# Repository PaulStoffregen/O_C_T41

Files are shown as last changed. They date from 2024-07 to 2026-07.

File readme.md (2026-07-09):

# O_C T4.1 - Ornament and Crime with Teensy 4.1

Check out SynthDad's
[What's New and Improved video](https://www.youtube.com/watch?v=kT94mBjvVQI)
for demo of O_C T4.1 capability.

This repository is for DIY builders and engineers who wish to extend this
open source design.  For products you can simply buy, scroll down to
[Commercial Products](#commercial-products)below.

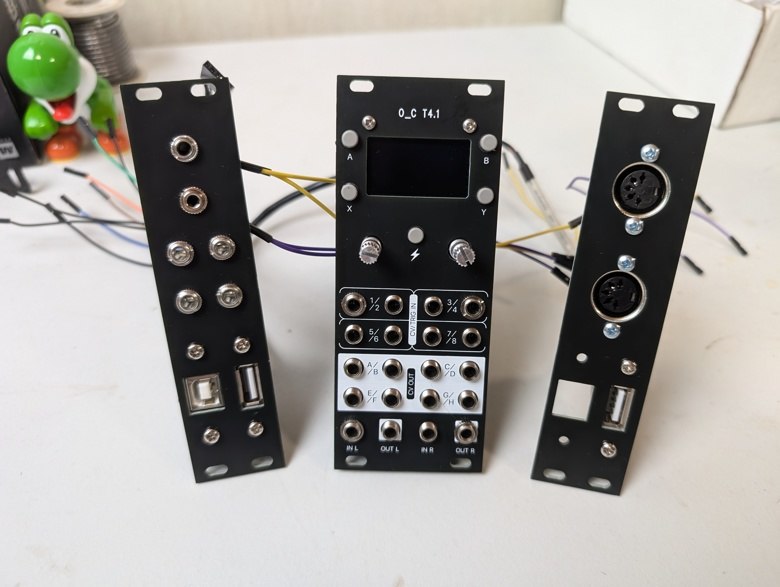
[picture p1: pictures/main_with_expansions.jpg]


While porting the Ornament and Crime code to run on Teensy 4, the question kept
coming up "what can a 600 MHz processor let me do".  Turns out the extra memory
allows [Phazerville firmware](https://github.com/djphazer/O_C-Phazerville)
to support all applets in a single image.  But the
original hardware designed for Teensy 3.2 limits what Teensy 4.0 can do.  The
necessity to share a single SPI port's bandwidth between the display and DAC
chip is the main limit.

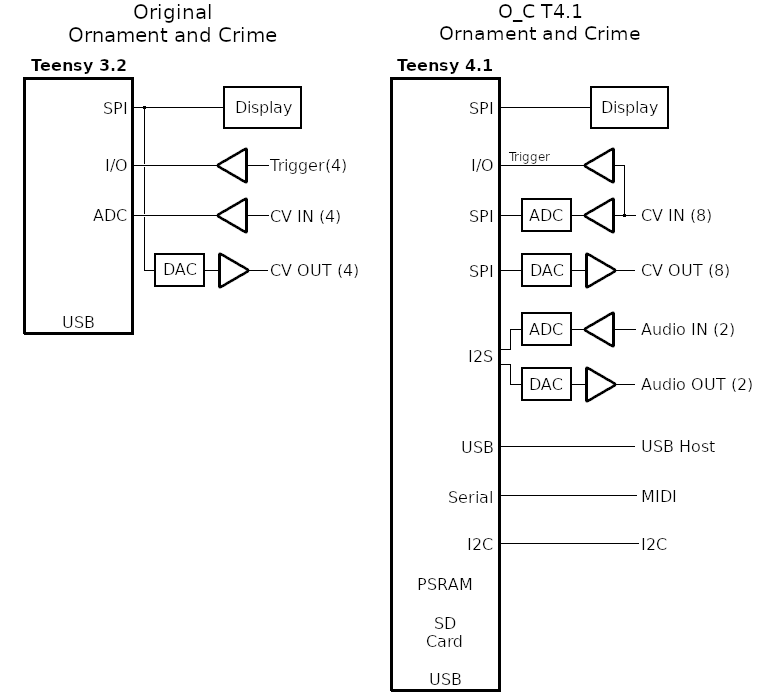
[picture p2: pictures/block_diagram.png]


O_C T4.1 was born to allow Teensy 4.1 to be fully utilized by Phazerville
firmware.  Control Voltage (CV) input and output was doubled to 8 signals.
An ADC chip was added for higher quality CV input, free from the on-chip
digital noise of a CPU.  Most importantly, three fully independent SPI port
are used for the display, CV inputs, and CV outputs.  Technically, the CV
input SPI is "FlexIO" which adds control of an analog mux chip.  All 3 have
fully independent bandwidth.

Audio input and output were also added, using fully independent bandwidth
of the I2S (digital audio) port.  Serial for MIDI, 480 Mbit/sec USB host,
and I2C for future expansion are also available on connectors meant for
expansion modules.

Additional memory can be added to Teensy 4.1, in the form of a PSRAM chip
give extra memory useful for audio effects, and a SD card for non-volatile
storage.  As with everything else, these have fully independent bandwidth.
Everything has optimal access for Teensy 4.1.  Phazerville leverages
optimized drivers with Direct Memory Access (DMA) for all of these peripherals.
O_C T4.1 truly is optimized to let Ornament and Crime make the most of
the powerful Teensy 4.1 processor!

# Attribution ShareAlike

Huge thanks & credit to mxmxmx who designed to the original Ornament and Crime module
so many years ago when Teensy 3.2 was new.

In 2023 mxmxmx waived the non-commercial license term for O_C T4.1, so the open source
license is now CC BY-SA 4.0.  Paul Stoffregen is not concerned about attribution,
but any O_C T4.1 Ornament and Crime product should give appropriate credit to mxmxmx.

If you see commercially sold O_C T4.1 without even a tiny footnote for attribution,
please send the vendor a gentle and polite reminder that attribution to mxmxmx is
required.

# Rev 3 issues:

Solder pads (7 pins) for the display should be raised approximately 1mm, towards the
top edge of the board.  To make the display fit, usually the 7 header pins need to
be bent slightly.

**3 beta testers had Teensy I/O pins damaged**, mostly encoders and pushbuttons.  If you build Rev 3, **USE A SOCKET** between Teensy and the CPU board.

Audio input clipping on 1 channel distorts other channel input - TODO: document resistors to change amplifier gain

Control board should allow more clearance for external trigger headers / wires

# Changes

Thanks to recent work by Beau Seidon, the files are now fully converted to KiCad for easier
editing to spin your own design.  Diode D6 added to protect U17 during unusual power startup.
Gerber files o_c_3_analog_new_jlc.zip and o_c_3_cpu_new_jlc.zip have been built and tested,
so you can simply build from known-good files.  Or you can use the KiCad files to make your
own design.

Capacitors C2, C3, C4, C5, C6, C7, C8, C9, C10, C11, C12 are not needed by newer Phazerville firmware.

# MIDI

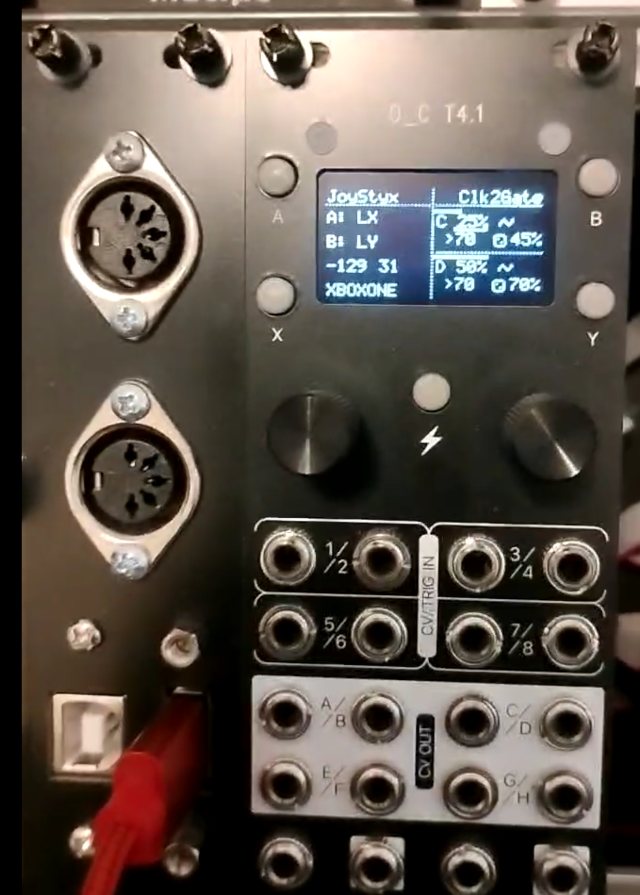
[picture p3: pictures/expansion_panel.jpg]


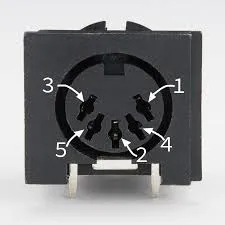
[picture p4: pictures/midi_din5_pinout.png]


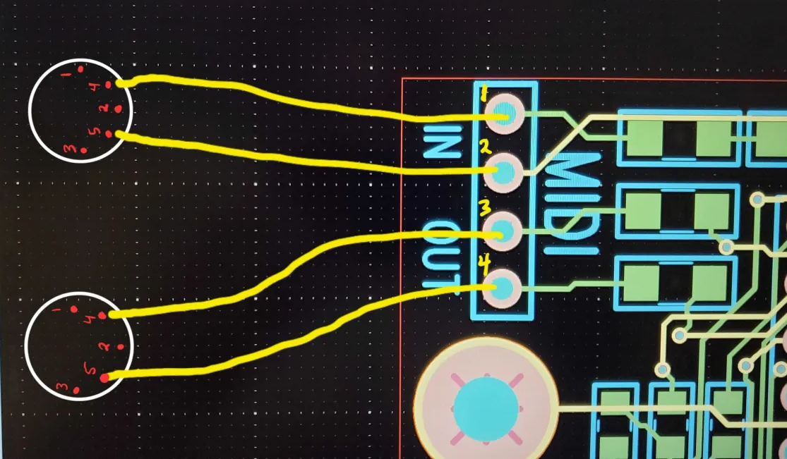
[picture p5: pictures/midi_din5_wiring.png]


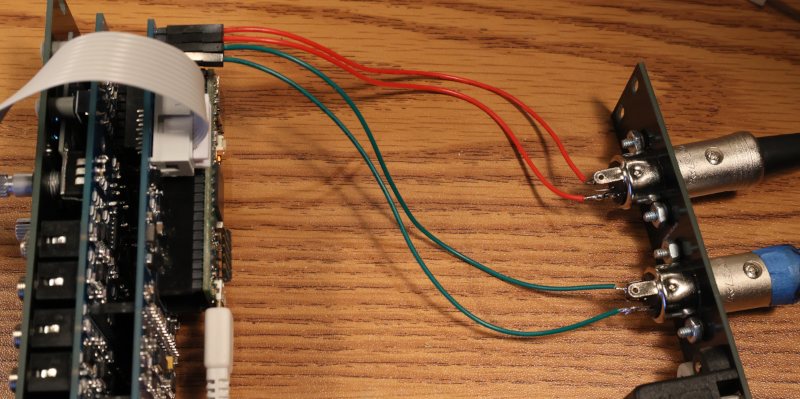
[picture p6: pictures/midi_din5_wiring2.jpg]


# Teensy Voltage and USB Host

O_C T4.1 rev3 uses a switching power supply to step down +12V modular power to
4.25V to run Teensy 4.1.  This voltage was chosen to reduce the load placed on
your +12V modular power rail.

However, when using USB host, Teensy 4.1 will supply about 4.1 volts to your
USB device.  This is below the 4.4V requirement of the USB 2.0 specification,
but most lower power USB devices which use a linear or step-down switcher to
3.3V typically can work.

If you want full 5 volt USB host power output, you have 2 options.

The best option is a powered USB hub, which also gives you the ability to
connect multiple USB devices!  If designing an add-on module, the USB hub chip
and power delivered to USB device would be best sourced from the modular +5V
power rail, generally meant for digital circuitry.  USB hub chips with
"Multiple Transaction Translators" (MTT) give better performance than "Single
Transaction Translator".  CH334 from WCH is a very low cost MTT hub chip
to consider, usually in stock at LCSC.

Or you can modify the O_C T4.1 power supply to provide 5V rather than 4.25V.
The trade off is O_C T4.1 will consume more power, because Teensy 4.1 uses
a linear regulator.  If using power hungry USB devices, they will also be
powered via the modular +12V rail, generally meant for analog circuitry.
The small step-down regulator on O_C T4.1 rev3 is limited to 600mA.  Teensy
4.1 typically consumes 110mA, but if a SD card is used it will also draw
current, leaving less available for USB devices.
To modify for 5V, if using the old gerber files add D6 by soldering on top
of C59.  Then increase R127 to 27K to change the power supply voltage.  If
using MIDI OUT, change R139 and R140 to 120 ohms for proper MIDI current.

# USB Host

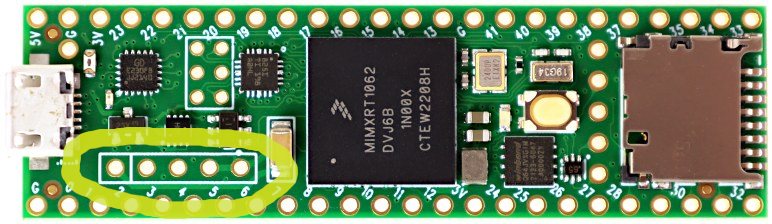
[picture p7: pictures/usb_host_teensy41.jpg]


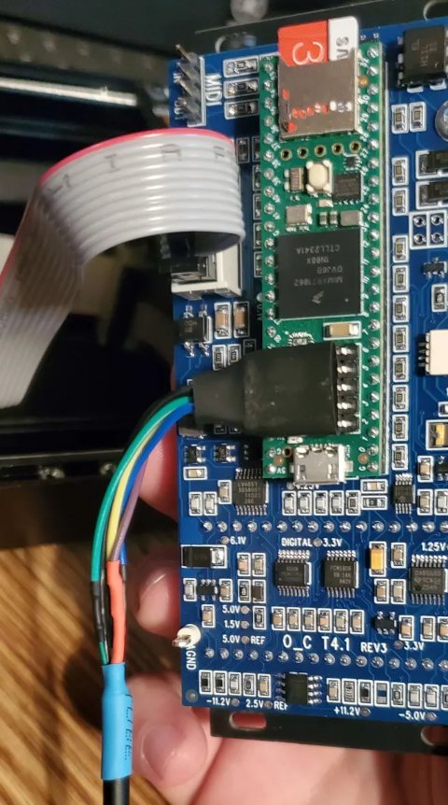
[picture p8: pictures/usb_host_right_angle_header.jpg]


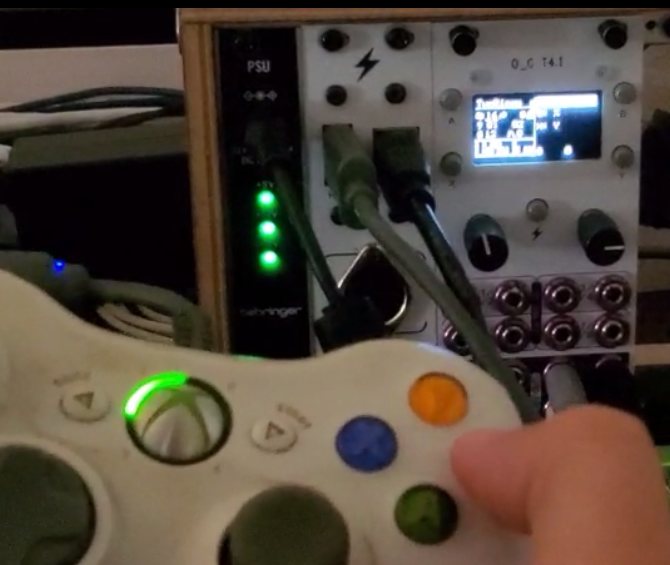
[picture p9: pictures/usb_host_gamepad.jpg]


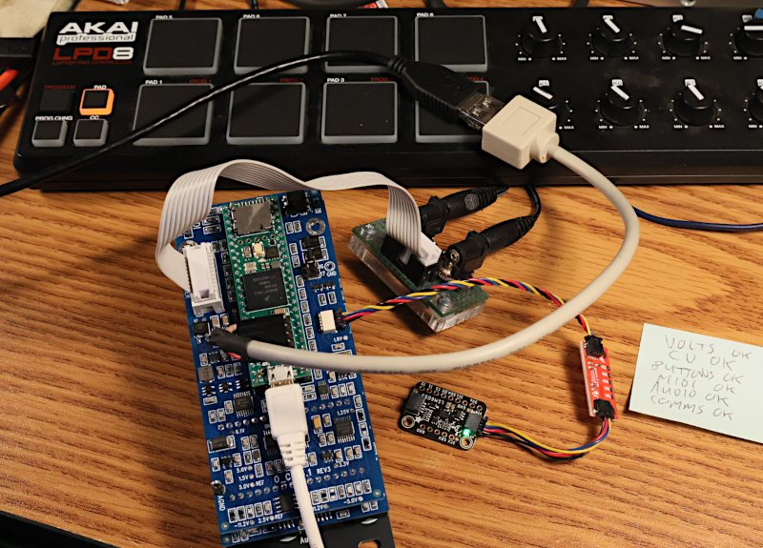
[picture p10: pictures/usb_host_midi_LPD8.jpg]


[USB Host Cable at SparkFun](https://www.sparkfun.com/usb-host-cable-for-teensy-4-1-and-teensy-3-6.html) - For connecting MIDI instruments, Gamepad controllers, maybe other stuff as software support develops...

[USB Device Cable at AdaFruit](https://www.adafruit.com/product/937) - For connecting to your PC or Mac, for upgrading [Phazerville firmware](https://github.com/djphazer/O_C-Phazerville), O_C can act as a MIDI device, and to run the [screen capture program](https://github.com/PaulStoffregen/Phazerville-Screen-Capture).

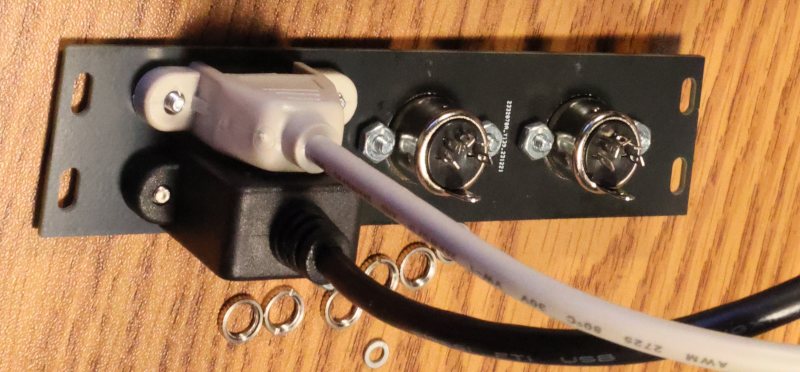
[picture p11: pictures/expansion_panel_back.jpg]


# Additional Memory

Phazerville can use additional memory for audio delay effects.  This
[8MB PSRAM](https://www.sparkfun.com/8-mbyte-psram-chip.html) (ApMemory
part number APS6404L_3SQR) or this
[larger 16MB PSRAM](https://protosupplies.com/product/psram_16mb/)
(ISSI part number IS66WVS16M8FBLL-104NLI) are supported.

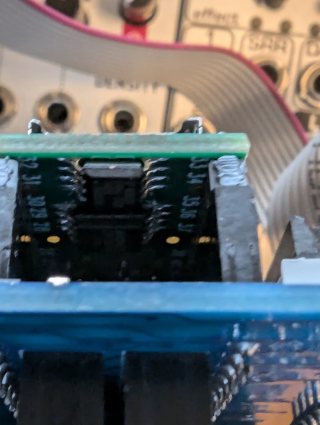
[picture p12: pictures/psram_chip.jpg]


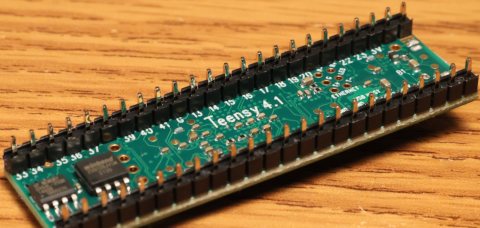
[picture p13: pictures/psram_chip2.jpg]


1 or 2 PSRAM chips can be added to Teensy 4.1.  If only 1 is added,
it must be soldered to the smaller location at the edge of the board
near pins 31-34.

# External Trigger

Normally the 4 trigger inputs are connected (shared) to CV1-CV4.

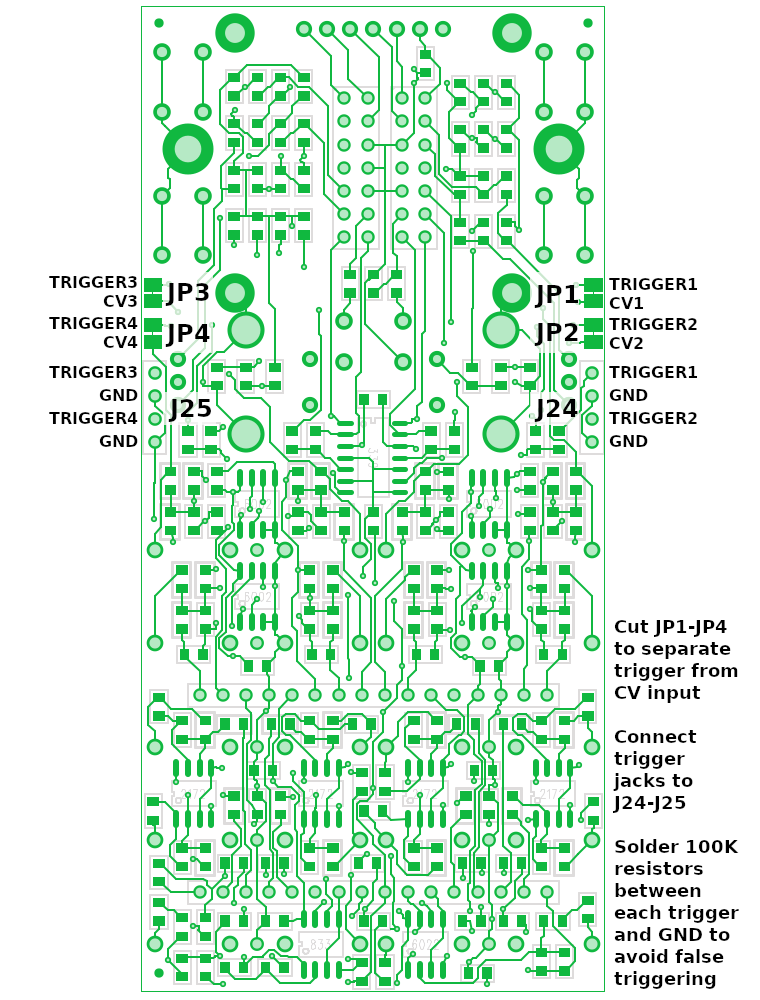
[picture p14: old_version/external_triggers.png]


You can modify the hardware to separate the triggers from CV1-CV4.

Cut JP1-JP4 apart to disconnect the triggers from CV1-CV4.  Then
wire external trigger jacks to J24 and J25.  100K resistors are
also recommended between each trigger input and GND, to prevent
false triggering when the cable is "floating".

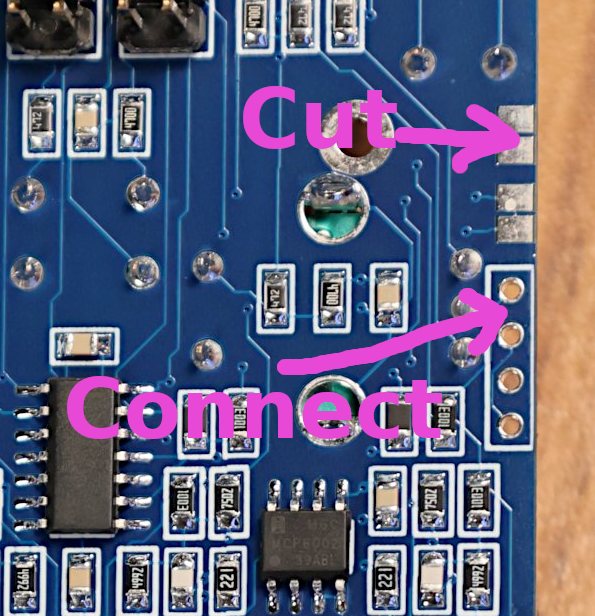
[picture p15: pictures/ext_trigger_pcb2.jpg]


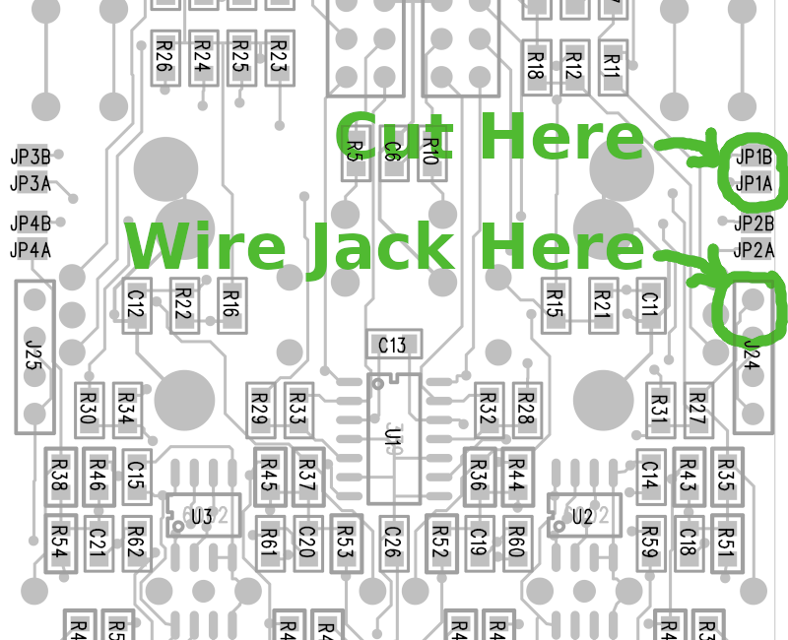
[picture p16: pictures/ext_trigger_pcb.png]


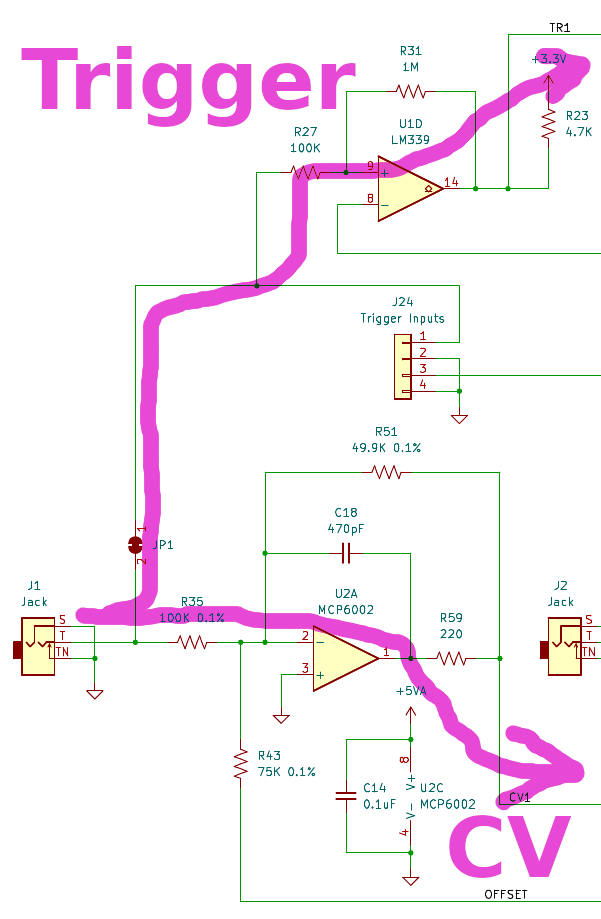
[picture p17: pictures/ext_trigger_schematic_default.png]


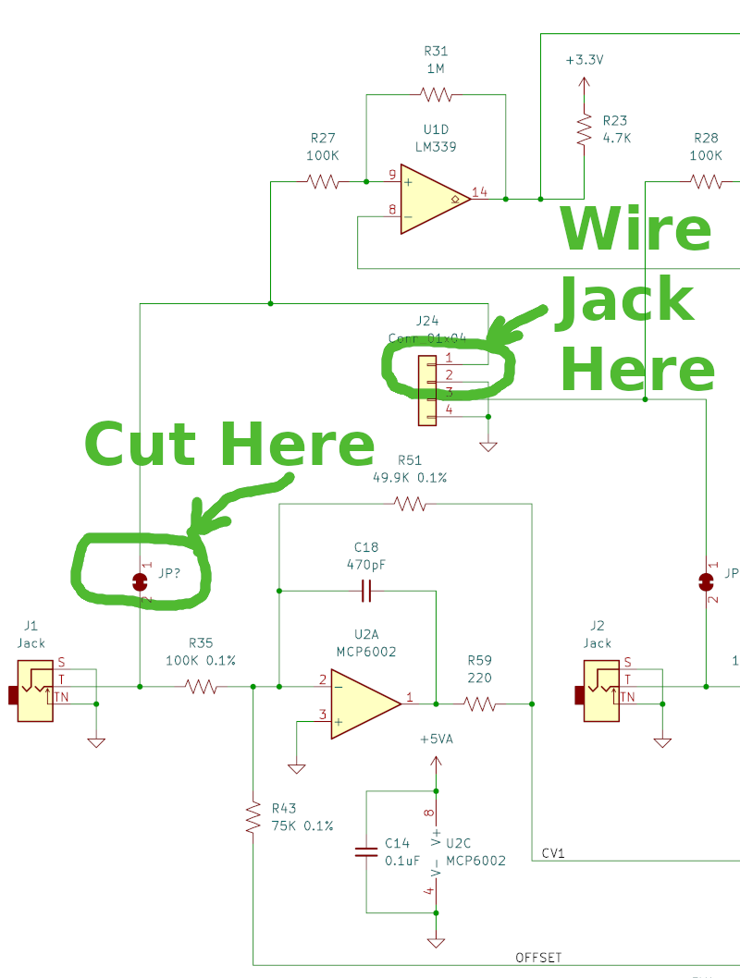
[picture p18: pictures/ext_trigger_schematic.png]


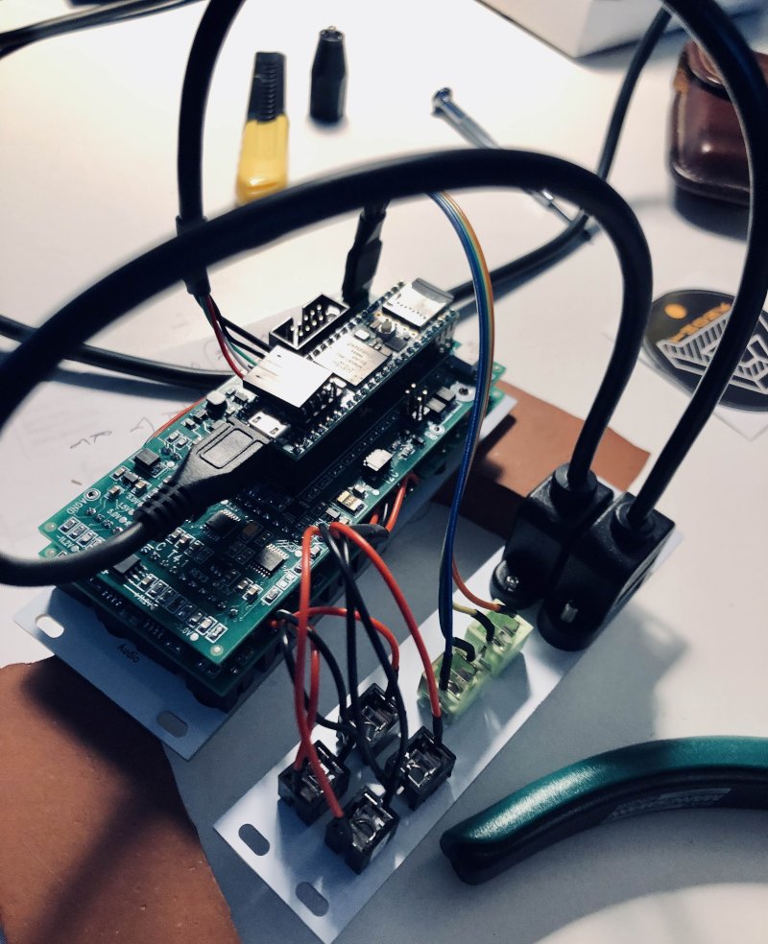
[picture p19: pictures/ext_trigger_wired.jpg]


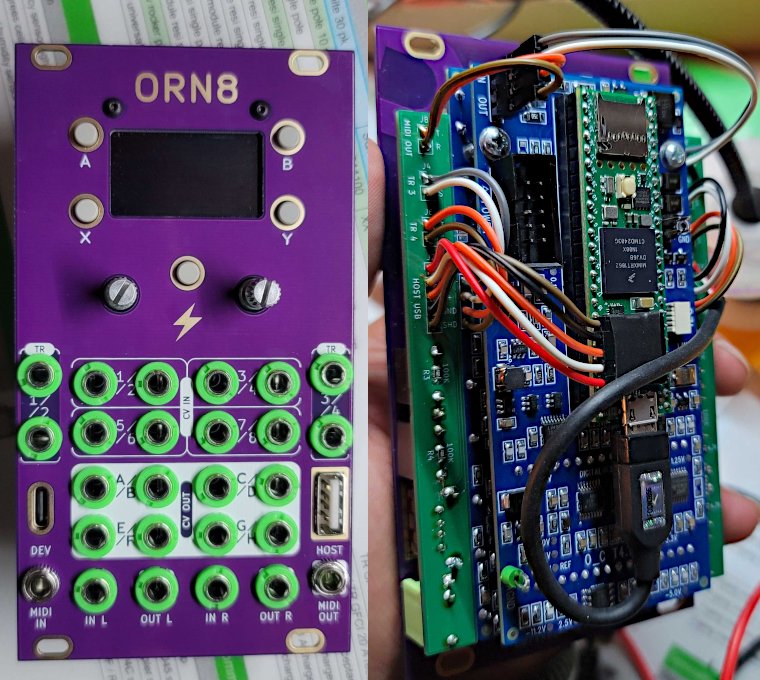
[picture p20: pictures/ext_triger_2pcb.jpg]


# Commercial Products

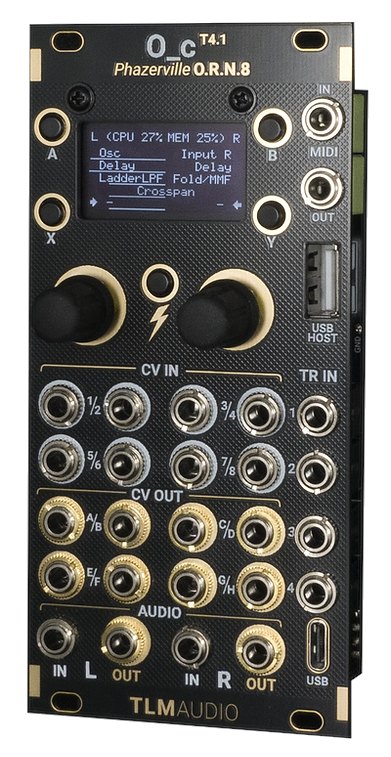
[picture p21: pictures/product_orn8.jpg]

[OC T.1 Phaserville O.R.N.8 by TLM Audio](https://www.tlm-audio.com/product-page/oc-4-1-phazerville)

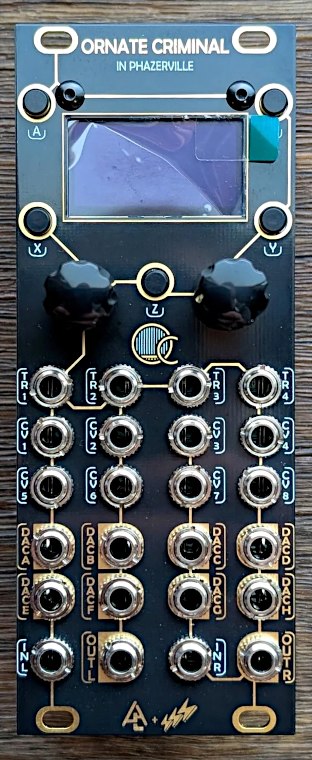
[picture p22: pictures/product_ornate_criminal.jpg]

[Ornate Criminal by After Later Audio](https://afterlateraudio.com/products/ornate-criminal)

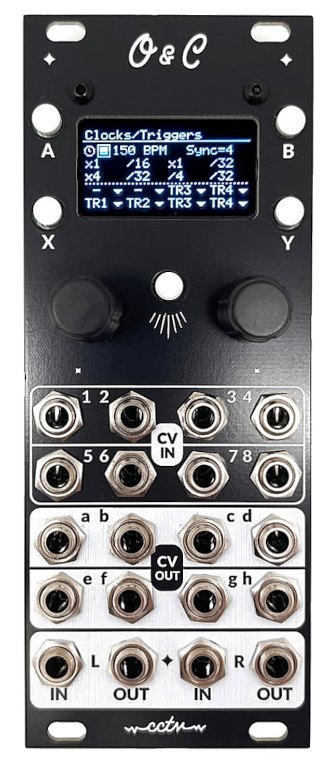
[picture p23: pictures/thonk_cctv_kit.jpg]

[Thonk CCTV Full DIY Kit](https://www.thonk.co.uk/shop/cctv-ornament-and-crime/) with [build guide](https://www.cctv.fm/post/ornament-and-crime-v4-1-build-guide)

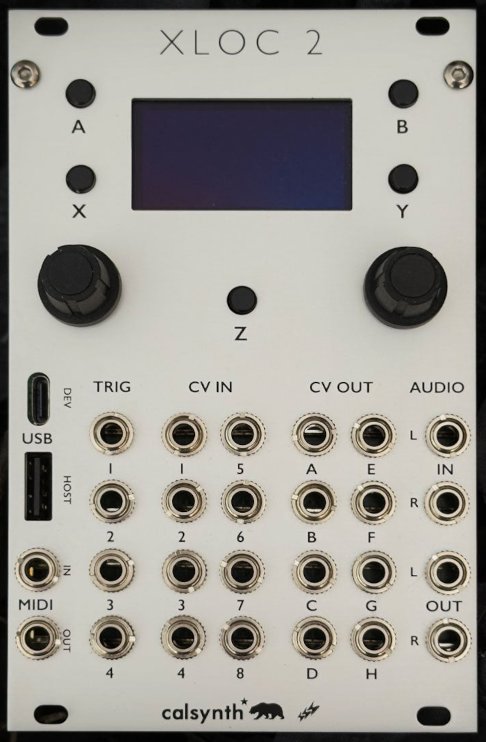
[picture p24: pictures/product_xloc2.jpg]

[XLOC2 by Calsynth](https://calsynth.com/products/xloc2-preorder-calsynth-exclusive-next-gen-4-1-ornament-and-crime-special-intro-price)

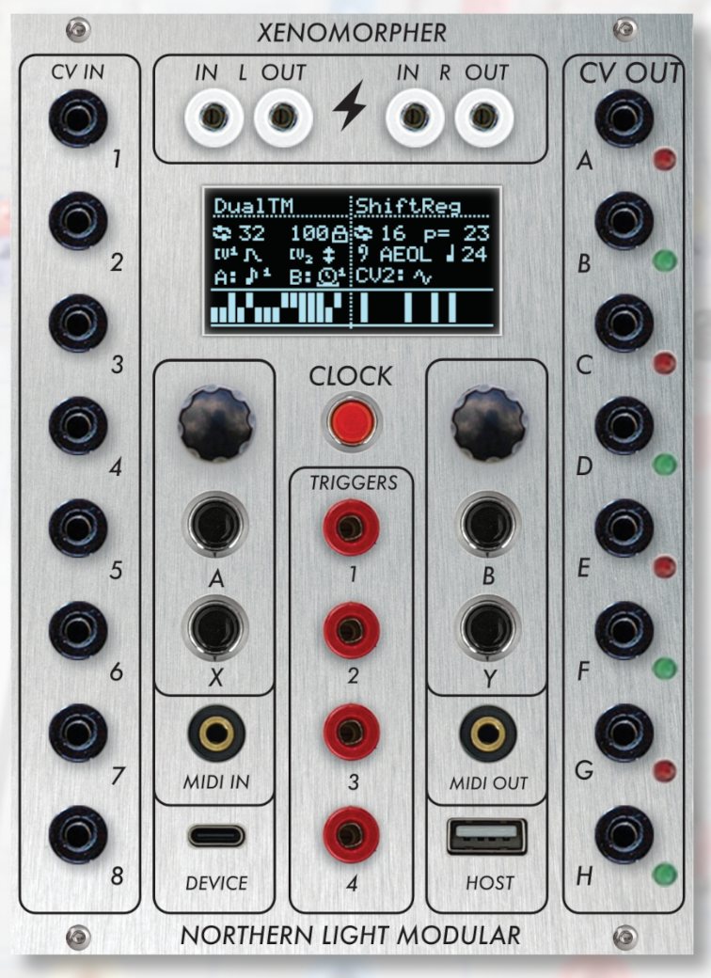
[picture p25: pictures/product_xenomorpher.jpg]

[Xenomorpher by Northern Light Modular](https://northernlightmodular.com/product/sx0/)

# Test Points For Troubleshooting

The control board has 14 test points to help you diagnose hardware problems.
Use a DC voltmeter with the negative lead connected to AGND, then carefully
touch the test points with the positive lead with care not to accidentally
also touch nearby parts.

Tests can be done with the analog board connected or removed.  If signals
which connect to the analog board read zero or a very low number, short
circuits or other problems might be on the analog board.  Removing it and
checking whether the voltages returns to normal may help localize the issue.

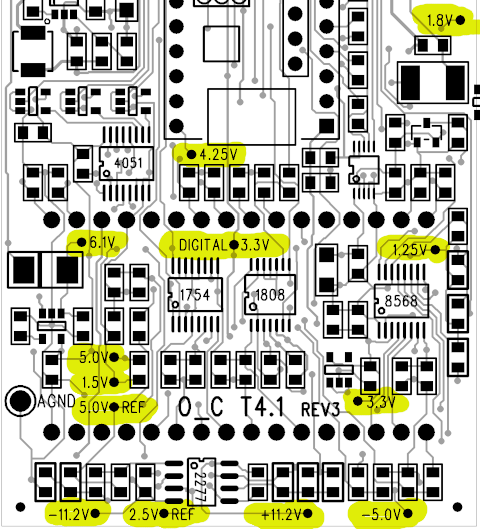
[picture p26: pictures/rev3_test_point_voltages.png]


Testing the voltages in this order usually makes the most sense.

## 11.2V and -11.2V (TP13 and TP12)

These are your Eurorack power after passing through the D1 diodes which
allow plugging the 10 pin power cable in either direction.  Normally
you would expect to see a slightly smaller (absolute) number for 11.2V
than -11.2V because more current is consumed from +12V.  But the actual
numbers you see will depend on your Eurorack power supply.

## 4.25V (TP5)

Main input power for Teensy 4.1, the 1.3 inch display, and MIDI:
This is created by U13, L1, L2, R126, R127, R128, R129, C53, C74, C92.

## DIGITAL 3.3V (TP8)

Main digital power: Teensy 4.1 creates this 3.3V power for digital
circuitry using the 4.25V main power.

## 0.1V (TP15)

Identification voltage for O_C T4.1 rev 3 hardware: Phazerville
firmware reads this voltage at startup to "know" which circuit board
you have built.  The voltage is created by R121 and R130.

Optionally R202 can be soldered to increase the ID voltage.  Normally
this would only be done if substantially modifying the hardware to
another configuration
[Phazerville firmware](https://github.com/djphazer/O_C-Phazerville)
supports.  This
[list of ID voltages](https://github.com/djphazer/O_C-Phazerville/wiki/ORN8-HW_ID-Voltages)
documents how the firmware responds to other voltages.

## 6.1V (TP6)

Analog input power: this is the power input to voltage regulators
which power sensitive analog circuitry.  It is created by diode
D2 and C69.  The exact voltage depends on your Eurorack power supply
and D2.  Any voltage between 6.7V to 5.5V is acceptable, because the
analog voltage regulators will create the actual analog power from
this unregulated input.

Diode D2 runs warm during normal operation.

## 5.0V and 3.3V (TP10 and TP7)

Analog power for analog input and output chips.  5.0V is created by
U14, C72, C76, C91, and 3.3V is created by U15, C60, C71, C78.

## 2.5V REF (TP3)

Primary 2.5V reference: This is the main reference voltage that is
the fundamental source for accuracy of all Control Voltage (CV) inputs
and outputs.  It is created by U19, C62, C79.  This voltage does not
turn on automatically at startup.  Phazerville fireware must configure
and enable it.  If you see no voltage, Teensy may not be running, or
Phazerville may be reading incorrect ID voltage which could cause it
to attempt use of a different chip, like the one used on original
Ornament and Crime with only 4 CV outputs.

## 1.8V (TP11)

Analog ADC power: This powers the ADC chip used for all 8 CV inputs.
It is created by U16, C58, C80.  This power is kept off until the
2.5V REF is active, because the U17 ADC chip has a self calibration
feature which only works properly if its other power sources start
up earlier.

## 5.0V REF (TP2)

Analog ADC reference: This is the voltage reference used by the ADC
chip for accuracy of all CV inputs.  It is created from 2.5V REF by
U26, R118, R136, R137, C59, C92, C93, L3, D6.

## 1.25V (TP9)

Analog CV Output Bias: All CV output amplifiers on the analog board
use this voltage to convert the DAC chip (U19) positive-only voltages
to Control Voltage which may be positive or negative.  It is created
from 2.5V REF by R133, R134, R61.

Optionally R200 can be soldered to modify CV output voltage range.
Normally this modification would be used with
[Squares and Circles](https://github.com/eh2k/squares-and-circles)
firmware.

## -5.0V (TP1)

Analog CV Input Offset: All CV input amplifiers on the analog board
use this offset voltage to convert Control Voltage which can be
positive or negative to the positive-only range of the ADC input
chips (U17 and U18).  It is created from 2.5V REF by U26, R135, R138.

Optionally R201 can be soldered to modify CV input voltage range.
Normally this modification would be used with
[Squares and Circles](https://github.com/eh2k/squares-and-circles)
firmware.

## 1.5V (TP14)

Trigger Threshold: All 4 trigger inputs use this voltage to define
the difference between off and on.  Actual triggering uses ~10%
hysteresis, so the off-to-on threshold will be slightly higher than
this voltage, and the on-to-off wil be slightly lower.  Hysteresis
is meant to prevent false triggering with analog signals close to
the threshold, especially if they have slight noise or modulation.

# CV Output Troubleshooting

If your CV outputs are not working properly, voltage passed between
the front analog board and the back side control board can be measured.

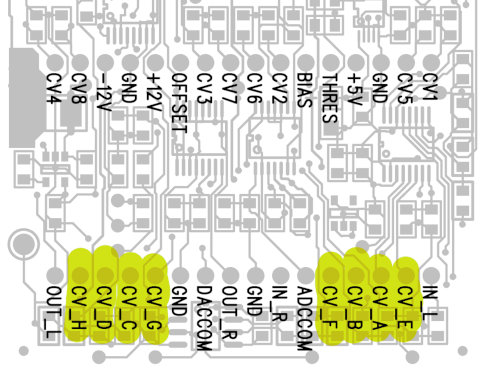
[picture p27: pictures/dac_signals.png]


The goal is to figure out whether a problem with CV output exists on
the analog board or control board.

These DAC voltage range from 0 to 2.5 volts.  The analog board multiplies
by -4 (inverts) and adds an offset, so 0 to 2.5V maps approx to 6.5V to -3.5V.

The control board can be powered without the analog board.  Even though
the display and pushbuttons are lost, which limits what you can do, a
problem where a short or low impedance on the analog board forces the
DAC signal low (which might at first seem to be a problem on the control
board) would disappear with the DAC signal returning to normal without
the analog board attached.

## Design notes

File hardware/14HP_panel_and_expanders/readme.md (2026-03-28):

## Front Panel

There are 4 choices for the front panel. Two are "ornate" with swirly background decorations (they look great in purple), and two have flat backgrounds without texture.

All are dual-sided/invertable in case you want to use the module with the jacks at the top and the screen at the bottom.

In each pair, you will find a USB-A and USB-C label which indicates the shape of the cutout for the host socket.

- If you choose a panel with a USB-A host port, you may need to provide a comment with your order: a note to the fabricator stating that the rectangular cutout in the EdgeCuts/KO layer overlapping the oblong hole near the "Host" silkscreen label IS intentional.
- The cutout in the finished product should be rectangular to accomodate a USB-A socket, the overlapping PTH is only there to ensure the cutout gets plated. If there is a better way to accomplish this in KiCad, please open an Issue with your recommendations!

        Note: In the batch I purchased from OSHPark, they did not cut out the rectangular USB slots, just the oblong drill holes. I had to finish them myself with a rotary tool and a file but they turned out petty much ok. It was tedious and I had to be very careful, and the result wasn't as sleek as those done at the fab shop, but nobody can tell from across the room. JLCPCB has cut them properly and plated the slots every time.

## Expanders

If you choose a panel with a USB-C host port, you may use the same 2 HP expander PCB on both sides, but you must pay attention to the resistor requirements for the USB-C CC pins:

- The DEV port requires **pull-downs**: connect the CC pins to ground through resistors with the USB-C standard value of 5.1k Ohms.

- The HOST port requires **pull-ups**: connect the CC pins to VBUS through resistors with a value corresponding to the VBUS voltage on the Teensy. (Rev3.x is designed with 4.2 Volts on VBUS, but you may hack your module to use 5 Volts which will change the resistors used here.)
    - For the default 4.2 Volts, use 45.3k Ohm resistors
    - For 5 Volt-modded modules, use the USB-C standard 56k Ohm.

The USB-A expander doesn't care about all that.

There is a jumper pad on the backside of both expanders near the MIDI jack. Bridging the pads with solder will connect the MIDI shield pin to ground. Only do this for the MIDI Out jack.

If you flip your module, you may have to swap the expanders to the opposite side, and reconnect some wires. Just pay attention what connects where, and use the labels on the front panel as a guide.

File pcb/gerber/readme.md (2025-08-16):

# Update

One set of boards made from the new gerber files (o_c_3_analog_new_jlc.zip and o_c_3_cpu_new_jlc.zip) has been verified, except for the pushbuttons.  Everything worked (expect the pushbuttons weren't tested).  This message will be updated when Digikey delivers more pushbuttons.

Diode D6 was added to protect U17 during unusual power startup conditions.  Use the "new" gerber files, or with the "old" files solder D6 on top of C59.

Capacitors C2, C3, C4, C5, C6, C7, C8, C9, C10, C11, C12 are not needed.  Best to leave these locations unpopulated.

# WARNING

3 beta testers reported damanging the Teensy 4.1.

If you build hardware using these Rev 3 files, **USE A SOCKET** between Teensy and the CPU board.

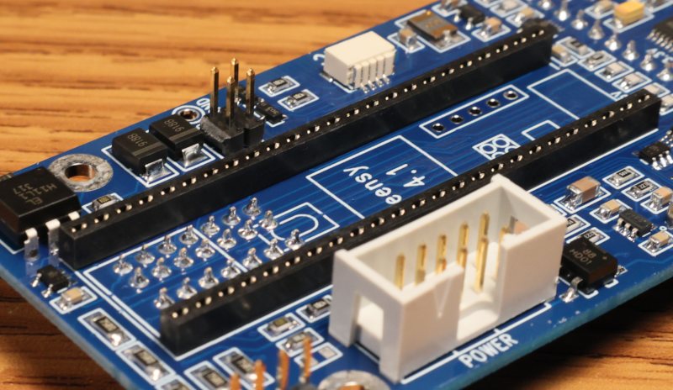
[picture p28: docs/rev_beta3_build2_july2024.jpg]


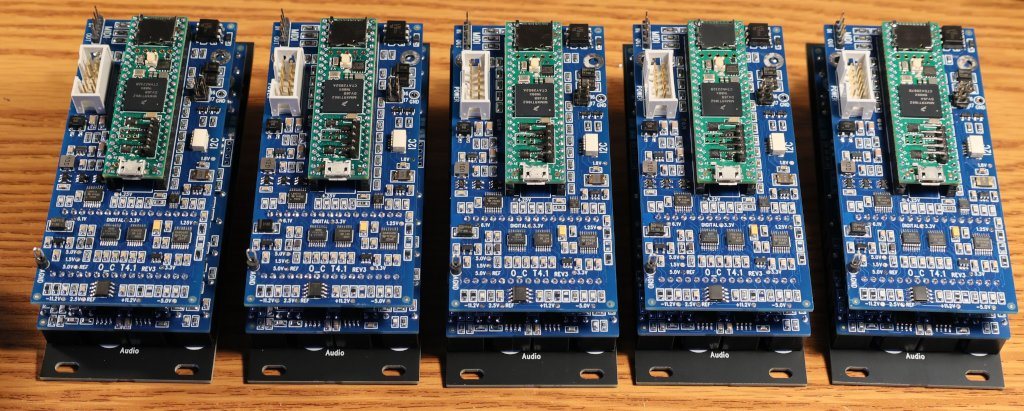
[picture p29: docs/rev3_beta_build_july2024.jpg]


# Test Point Voltages



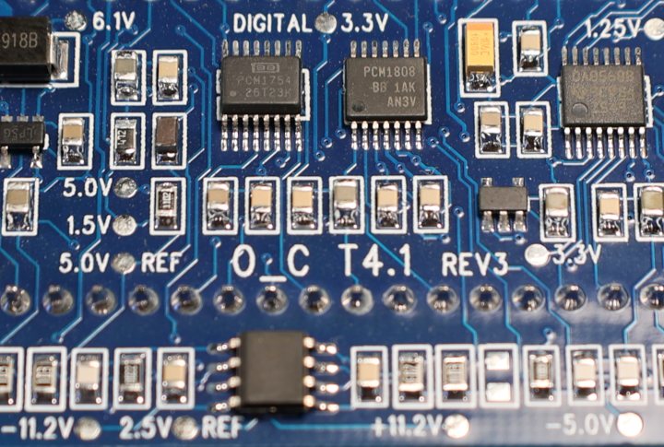
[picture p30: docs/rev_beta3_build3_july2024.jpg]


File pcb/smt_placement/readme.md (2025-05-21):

These KiCad files contributed by Angia on Discord have parts placement only.  They are **NOT** full KiCad layout files for Rev 3.

"I did create placement for the SMT components in Kicad for SMTA purposes and I'd be happy to share that here if it helps someone get going.  Honestly idk how much help this would be but enjoy."

analog_rev3_SMTA.zip
control_rev3_SMTA.zip

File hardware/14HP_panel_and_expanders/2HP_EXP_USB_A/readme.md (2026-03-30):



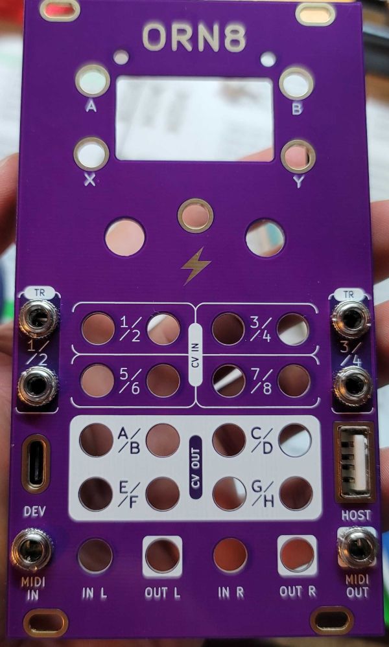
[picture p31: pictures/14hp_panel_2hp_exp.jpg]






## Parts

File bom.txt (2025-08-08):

Preliminary Info - CAUTION: may change!

Additional BOM pages with more info:
  https://www.mouser.com/ProjectManager/ProjectDetail.aspx?AccessID=61d2510573
  https://docs.google.com/spreadsheets/d/1lMKtp5o-q9ivLl7gmPvncQ6gjRCvjwu5SlCP15zF1qo/edit?usp=sharing

Analog Board		Control Board	Qty	Part
------------		-------------	---	----
C34-C41			C92		9	Capacitor 22pF, NP0, 5%, 0805   CC0805JRNPO9BN220
C46-C47					2	Capacitor 47pF, NP0, 5%, 0805   CC0805JRNPO9BN470
C18-C25					8	Capacitor 470pF, NP0, 5%, 0805  CC0805JRNPO9BN471
			C81-C90		10	Capacitor 680pF, NP0, 5%, 0805  CC0805JRNPO9BN681
C44-C45					2	Capacitor 1nF, NP0, 5%, 0805    CL21C102JBCNFNC CC0805JRNPO9BN102
C42-C43					2	Capacitor 8.2nF, NP0, 5%, 0805	GRM2195C2A822JA01D
C7-C10			C91		5	Capacitor 10nF, X7R, 0805  CC0805JRX7R9BB103 GRM2195C1H103JA01D
C2-C6,C11-C17,C26-C33	C52-C68,C94	38	Capacitor 0.1uF, X7R, 0805  CC0805JRX7R9BB104
C1,C50-C51		C69-C73		8	Capacitor 1.0uF, X7R, 0805
C48-C49			C74-C80		9	Capacitor 10uF, X5R, 0805  CL21A106KOQNNNG  TMK212BBJ106KG-T
			C93		1	Capacitor 10uF, Tantalum, 1206  TAJA106K016RNJ
			C95-C97		3	Capacitor 22uF, X5R, 25V, 1206  CL31A226KAHNNNE
			D1		1	Diode, Bridge Rectifier, HD01-T
			D2-D4		3	Diode, Zener, 5.1V, 3W, 1SMB5918B
			D5		1	Diode, SOD123, 1N4148W-TP
			D6		1	Diode, Zener, 5.1V 2%, 0.2W, SOD323, BZT52B5V1S  BZT52B5V1JS-TP  BZT52-B5V1S_R1_00001
			F1		1	PTC Fuse, 100mA, 1812  MF-MSMF010-2
J1-J20					20	Jack, mono 3.5mm, PJ-301M
J21					1	OLED Display, 1.3 inch
J22-J23					2	Header, 7x2
J26-J27					2	Header, 16x1
			J28-J29		2	Socket, 7x2  (omit if soldering boards together)
			J30-J31		2	Socket, 16x1  (omit if soldering boards together)
			J32		1	Header, 5x2 Shrouded
			J33		1	Header, 4x1
			J34-J35		2	Header, 2x1 (omit if debug signals not needed)
			J36-J37		2	Test Point (omit if not needed)  Keystone 5011
			J38		1	Connector, JST 4 pin, Sparkfun QWIIC PRT-14417
			L1		1	Inductor, Ferrite Bead, 0.5A, 600ohm  HZ0805E601R-10
			L2		1	Inductor, 10uH, 1A, 4mm  BCIHP0420SC-100M  ASPI-4030S-100M-T  LQH44NN100K03L  LQH44PH100MPRL  CY43-10UH  MDA4020-100M  IFSC1515AHER100M01
			L3		1	Inductor, 1.5uH, 1A, 0805  BRC2012T1R5MD
			Q1-Q2		2	Mosfet, N-ch, SOT23  FDV303N
			R144		1	Resistor 0 ohm jumper, 0805
			R139-R143	5	Resistor 75, 1%, 1/4W, 1206  (5% ok)  CRCW120675R0FKEAC SR1206JR-7W75RL
			R103-R117	15	Resistor 100, 1%, 0805  (5% ok)  RC0805FR-07100RL
R59-R66,R83-R92		R118		19	Resistor 220, 1%, 0805  (5% ok)  RC0805FR-07220RL
R6-R10,R17-R22		R119		11	Resistor 470, 1%, 0805 RC0805FR-07470RL
			R131-R132	2	Resistor 1K, 1%, 0805  (5% ok)  C0603FR-071KL
R93-R94					2	Resistor 1.40K, 1%, 0805  RC0805FR-071K4L RT0805BRD071K4L
R95-R96					2	Resistor 2.21K, 1%, 0805  RC0805FR-072K21L RT0805BRD072K21L
R97-R98					2	Resistor 3.48K, 1%, 0805  RC0805FR-073K48L RT0805BRD073K48L
R1-R5,R11-R16,R23-R26	R120-R124	20	Resistor 4.7K, 1%, 0805 (5% ok, except R121,R124)  RC0805FR-074K7L
			R126		1	Resistor 5.11K, 1%, 0805  RC0805FR-075K11L
			R133-R137	5	Resistor 10K, 0.05%, 0805  ERA-6ARW103V  RT0805WRD0710KL
			R125		1	Resistor 11K, 1%, 0805  RC0805FR-0711KL
			R138		1	Resistor 20K, 0.05%, 0805  ERA-6ARW203V  RT0805WRD0720KL  AR05ATB2002  PTFR0805Q20K0N9
			R127-R128	2	Resistor 22K, 1%, 0805  RC0805FR-0722KL
R67-R74					8	Resistor 24.9K, 0.1%, 0805  RT0805BRD0724K9L  ARG05BTC2492
R101-R102				2	Resistor 31.6K, 1%, 0805   RC0805FR-0731K6L  RT0805BRD0731K6L
R51-R58					8	Resistor 49.9K, 0.1%, 0805  RT0805BRD0749K9L
R43-R50					8	Resistor 75K, 0.1%, 0805   RT0805BRD0775KLa
R27-R30,R99-R100			6	Resistor 100K, 1%, 0805  RC0805FR-07100KL
R35-R42,R75-R82				16	Resistor 100K, 0.1%, 0805  RT0805BRD07100KL
			R129-R130	2	Resistor 150K, 1%, 0805  RC0805FR-07150KL
R31-R34					4	Resistor 1M, 1%, 0805  (5% ok) RC0805FR-071ML
			R200-R202	0	Do not populate
SW1-SW5					5	Pushbutton + Cap, TL1105SPF100Q + 1RLGR (E-Switch)
SW6-SW7					2	Rotary Encoder, PEC11R-4220K-S0024
U1					1	IC, Voltage Comparator, SOIC14, LM339A
U2-U5					4	IC, Dual Opamp, SOIC8, MCP6002
U6-U9					4	IC, Dual Opamp, SOIC8, OPA2172 (TI) or GS2262-SR (Gainsil)
U10					1	IC, Dual Opamp, SOIC8, MCP6022
U11					1	IC, Dual Opamp, SOIC8, LM833
			U12		1	Teensy 4.1 (with headers and sockets)
					2	24 pin headers
					2	24 pin sockets - CRITICAL: USE A SOCKET so Teensy is replaceable!
					?	IC, optional PSRAM, APS6404L_3SQR, https://www.pjrc.com/store/psram.html
			U13		1	IC, Buck Converter, LMR54406FDBVR (do not use LMR54406DBVR)
			U14		1	IC, LDO 5V, LP2985A-50DBVRM3 or LP2985A-50DBVR or LP2985-50DBVR
			U15		1	IC, LDO 3.3V, TPS7A2033PDBVR or ADP150-3.3
			U16		1	IC, LDO 1.8V, LP5907MFX-1.8/NOPB (alternate NCV8163A)
			U17		1	IC, ADC, MCP33131D-05-E/MS
			U18		1	IC, analog mux, 74LV4051PW,118 or SN74LV4051APWR
			U19		1	IC, DAC, DAC8568IBPWR
			U20-U23		4	IC, Buffer level shifter, SN74LV1T125DBVR or 74LV1T125GVH
			U24		1	IC, Audio ADC, PCM1808PWR
			U25		1	IC, Audio DAC, PCM1754DBQR
			U26		1	IC, Dual Opamp, SOIC8, OPA2277UA (TI)  OPA2277M/TR (HGSemi)
			U27		1	Optocoupler, DIP6, H11L1

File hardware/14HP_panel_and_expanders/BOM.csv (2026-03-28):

2HP_EXT (USB-C):
Reference | Qty | Value | Description | PN | Link
J1 | 1 | DEV_USB | USB-C Socket | TYPC-14PLC-H10.0 / "10PCS Type-C-09" | https://www.sparkfun.com/sparkfun-usb-c-breakout-vertical.html & https://www.aliexpress.us/item/3256808414225667.html
J3, J5 | 2 | TR_1_JACK, TR_2_JACK | Jack, mono 3.5mm, PJ-301M | PJ-301M (WQP518MA) | https://www.thonk.co.uk/shop/3-5mm-jacks/
J7 | 1 | MIDI_IN | Jack, stereo 3.5mm, PJ366ST | PJ366ST | https://www.thonk.co.uk/shop/3-5mm-jacks/
R1,R2 | 2 | 5.1K | Resistor 5.1K, 1%, 0805 (device port only) | RC0805FR-075K1L | https://www.mouser.com/ProductDetail/YAGEO/RC0805FR-075K1L?qs=TvbiuNL4H85i1jCYhRJkKQ%3D%3D
R5,R6 | 2 | 45.3K | Resistor 45.3K, 1%, 0805 (host port only) | RC0805FR-0745K3L | https://www.mouser.com/ProductDetail/YAGEO/RC0805FR-0745K3L?qs=VLOqbHBAO5d7U6crc6tyKA%3D%3D
R3,R4 | 2 | 100K | Resistor 100K, 1%, 0805 | RC0805FR-07100KL | https://www.mouser.com/ProductDetail/YAGEO/RC0805FR-07100KL?qs=8Y8p%252BasKcI7rEWn6FcVdAA%3D%3D
2HP_EXT (USB-A):
Reference | Qty | Value | Description | PN | Link
J1 | 1 | HOST_USB | USB-A Socket | CR860-E ("Brown") | https://www.aliexpress.us/item/3256805906447314.html
J3, J5 | 2 | TR_3_JACK, TR_4_JACK | Jack, mono 3.5mm, PJ-301M | PJ-301M (WQP518MA) | https://www.thonk.co.uk/shop/3-5mm-jacks/
J7 | 1 | MIDI_OUT | Jack, stereo 3.5mm, PJ366ST | PJ366ST | https://www.thonk.co.uk/shop/3-5mm-jacks/
R3,R4 | 2 | 100K | Resistor 100K, 1%, 0805 | RC0805FR-07100KL | https://www.mouser.com/ProductDetail/YAGEO/RC0805FR-07100KL?qs=8Y8p%252BasKcI7rEWn6FcVdAA%3D%3D

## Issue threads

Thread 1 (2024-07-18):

Duplicate R119 on latest control_rev3 schematic

EddieHorn, 2024-07-18:
[control_rev3.pdf](https://github.com/user-attachments/files/16281441/control_rev3.pdf)
Hi Paul, Great work on the 4.1 board. I was looking at the schematic and noticed duplicate numbers for R119. I've marked them on attached .pdf

Best Regards
Eddie

PaulStoffregen, 2024-07-18:
Opps, the resistor connected to the opamp is really R118.

Fixed: https://github.com/PaulStoffregen/O_C_T41/commit/ca44bec0c4f43e6e52b65ad631a0cd9bf04813c8

PaulStoffregen, 2024-07-18:
PDF updated: https://github.com/PaulStoffregen/O_C_T41/commit/0aa44c64ca89e6f59608df03b721c48f74730e6b

Closed 2024-07-18.

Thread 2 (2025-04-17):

Rev3 Feedback & Suggestions

djphazer, 2025-04-17:
While assisting vendors in developing commercially viable iterations of this hardware design, we've addressed some concerns that I'd like to share for others:

## USB Host voltage
The Rev3 design only supplies about 4.2V to the Teensy. Without an external powered hub, this is inadequate for many devices to connect directly. To quote Paul from Discord discussions:

> If you change R128 to get more voltage (which does bring USB host voltage up), you should also increace  R116 and R117 so MIDI OUT current remains approx 5mA when driving the expected MIDI IN circuit of 220 ohms and 1.25V optocoupler LED.
> Indeed I chose R128 and R129 for about 4.25V.  This is at pretty much the low end of the range USB devices can use (and expected if running from an unpowered USB hub).  The 4.25V choice was motivated by desire to reduce the power draw from the Eurorack +12V power.
> If you're ok with higher overall power usage, perfectly fine to adjust R128 for voltage up to 5.25V.  Just remember 4.25V powers MIDI OUT, so adjust R116 and R117

## Audio input/output gain-staging
I recommend changing resistor values (R101 / R102) to reduce input gain to avoid distorting the PCM chip... 31.6K is tuned for 10Vpp (+/-5V), so something like ~15K would better accommodate 20Vpp Eurorack signals, maybe smaller for 24Vpp. Likewise, you might want more gain at the output stage. (I'm not sure what to alter for increased output gain...)

## Trigger inputs
By default, in Rev3, TR1-4 and CV1-4 share the same jacks, which I'd rather not have on any of the final designs. They should be broken out, with extra pulldown resistors (100K) in parallel. The PCB design allows for this, with extra pin headers and traces that can be cut... ALA successfully squeezed 4 extra jacks on the same 10hp front panel!
Flexible Input Mapping in the firmware provides a workaround to avoid collisions, but it can still be confusing.

More forum discussions here: https://modwiggler.com/forum/viewtopic.php?t=280365

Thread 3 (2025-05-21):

Are the current gerbers and boms working/usable?

michaeljohnbennett, 2025-05-21:
Hi there,

really interested to try this out with a 4.1 Teensy, are the current gerbers/pcbs ready to fab/workable with phazerville firmware?

Would love to help debug/test these out!

djphazer, 2025-05-21:
Working and usable? Absolutely. 💯 I've been playing many gigs with the Beta hardware!

Just make sure you've read and understood the caveats and advice in the README and in Issue #2

michaeljohnbennett, 2025-05-21:
fantastic thankyou!

I just wanted to be sure before I started on getting some fabbed to trial.

In terms of the gain resistors thats an easy enough fix but the trigger inputs and splitting out jacks is still a bit beyond me, the current PCB will work ok?

On the USB Voltage side, if I'm running this off a eurorack rail it will be fine as is?

New to electronics and the variations around resistors and voltages so any guidance would be appreciated, thankyou. My background is software design but starting to learn a bit more around electronics! And try to make music. Try.

michaeljohnbennett, 2025-05-21:
Is it possible to get a placement file for the SMDs etc or have you all prepared the units by hand once you got the boards back?

michaeljohnbennett, 2025-05-21:
I tried to open the schematic files in kicad 8 and 9 but they dont show anything in the PCB view and all the elements have no footprints.

what am I doing wrong here? Any pointers would be appreciated. thankyou.

PaulStoffregen, 2025-05-21:
PCB was designed with other software, so there absolutely no Kicad PCB info.

TFModular, 2025-05-22:
Hi which software was used to create the PCB?

michaeljohnbennett, 2025-05-25:
OK with a bit of help from modwigglers I got a working bom and placement files from the Kicads.

Its a bit of a 2 step process but it seems to be ok.

For the extension panel, is there a BOM or parts that work for the ports? I take it, from the gerbers, its just a face panel with a bunch of Midi and USB sockets attached? These then wire to the board respectively?

michaeljohnbennett, 2025-06-20:
I have built up the PCBA from gerbers and help from the community members! thankyou.

Closed 2025-06-20.

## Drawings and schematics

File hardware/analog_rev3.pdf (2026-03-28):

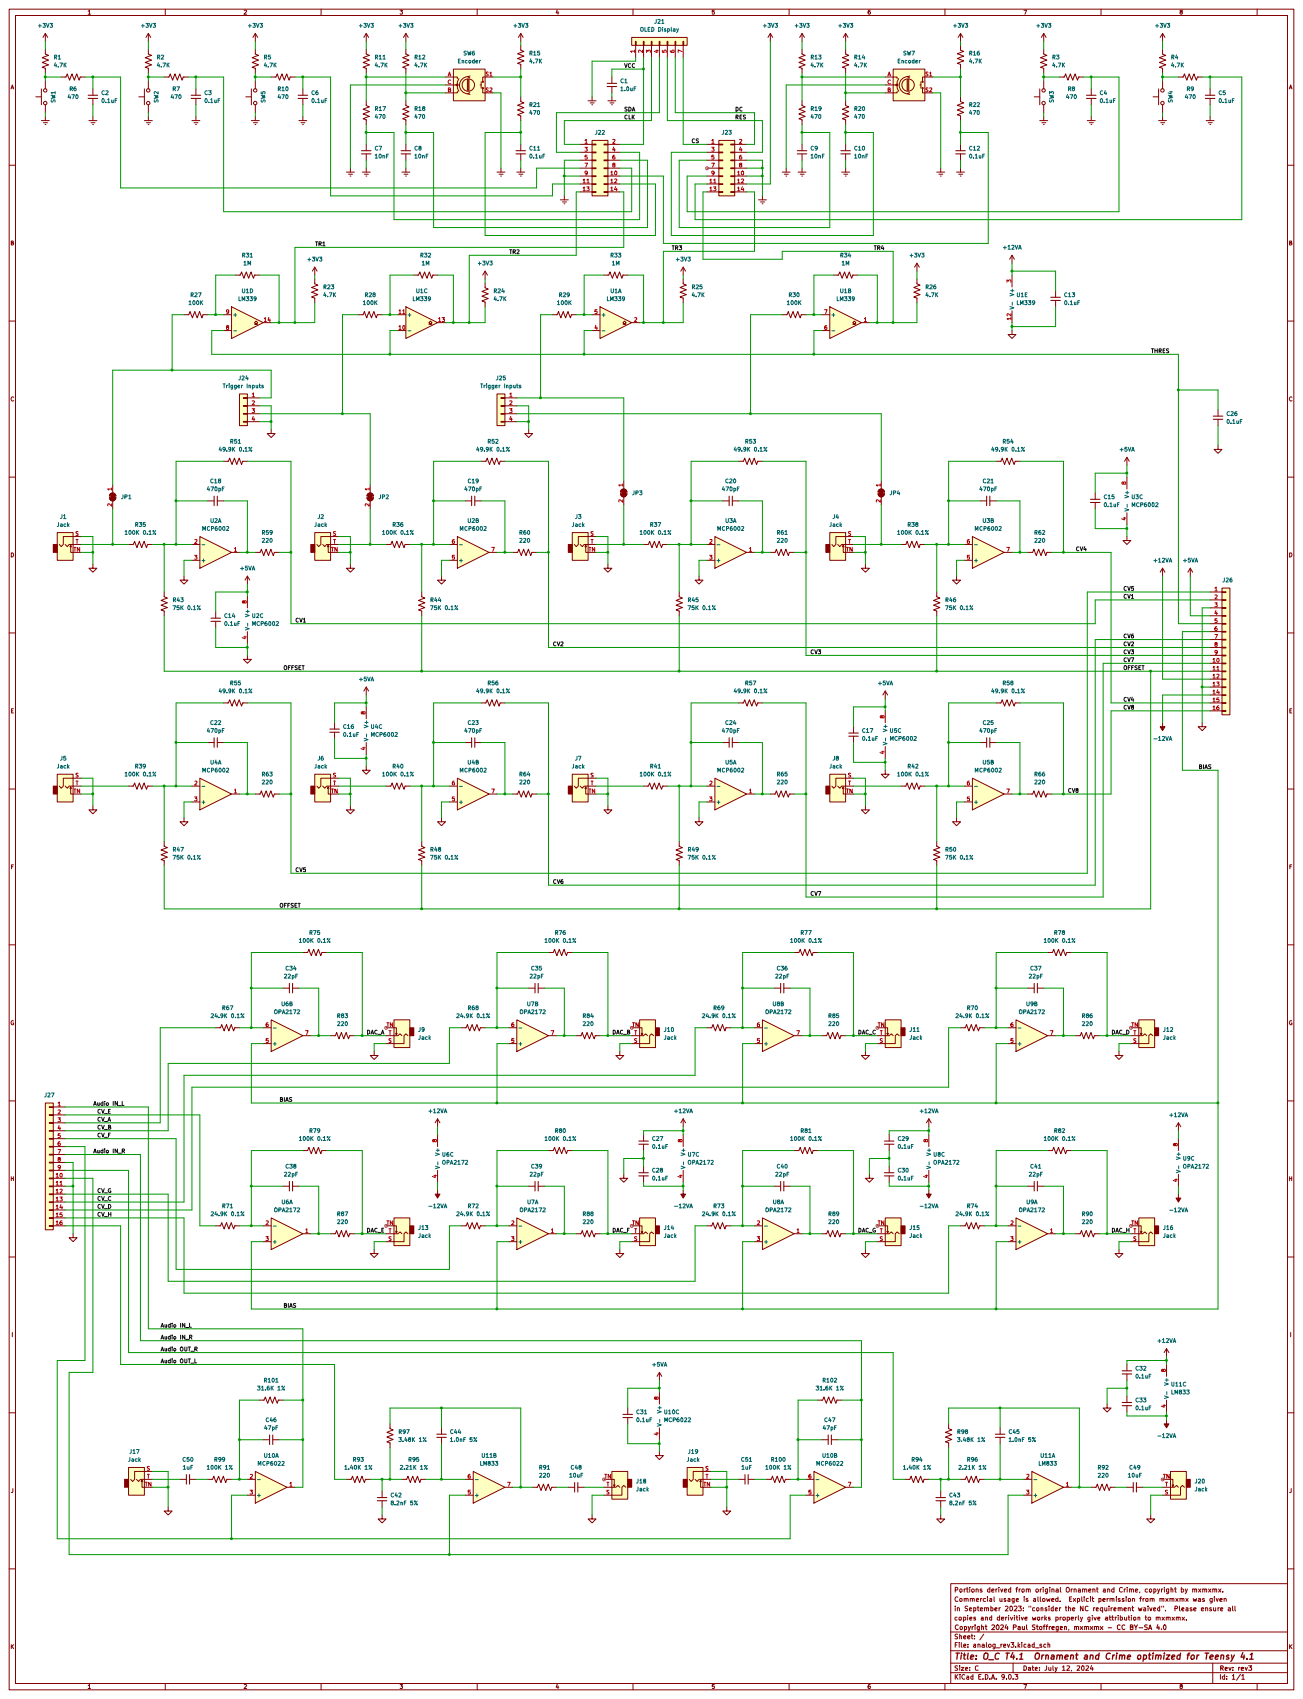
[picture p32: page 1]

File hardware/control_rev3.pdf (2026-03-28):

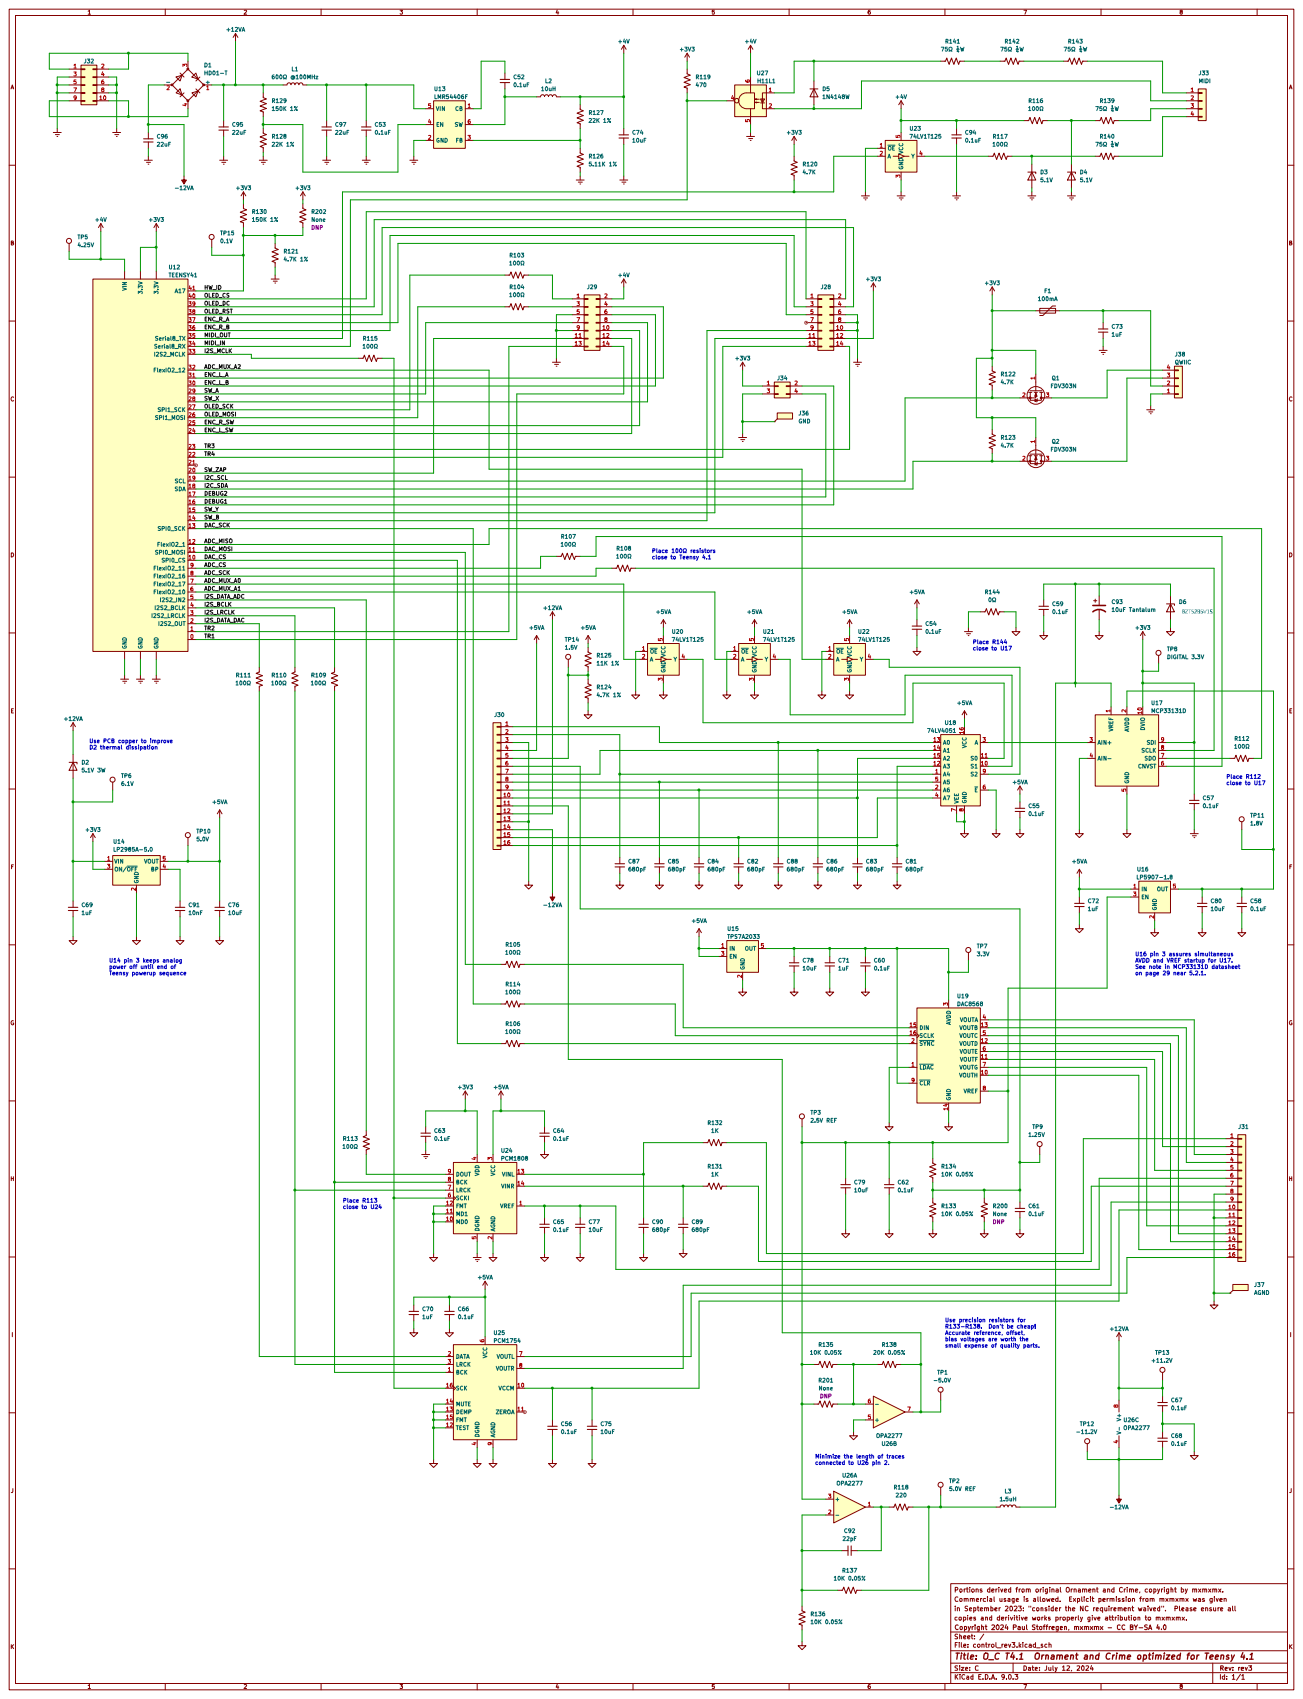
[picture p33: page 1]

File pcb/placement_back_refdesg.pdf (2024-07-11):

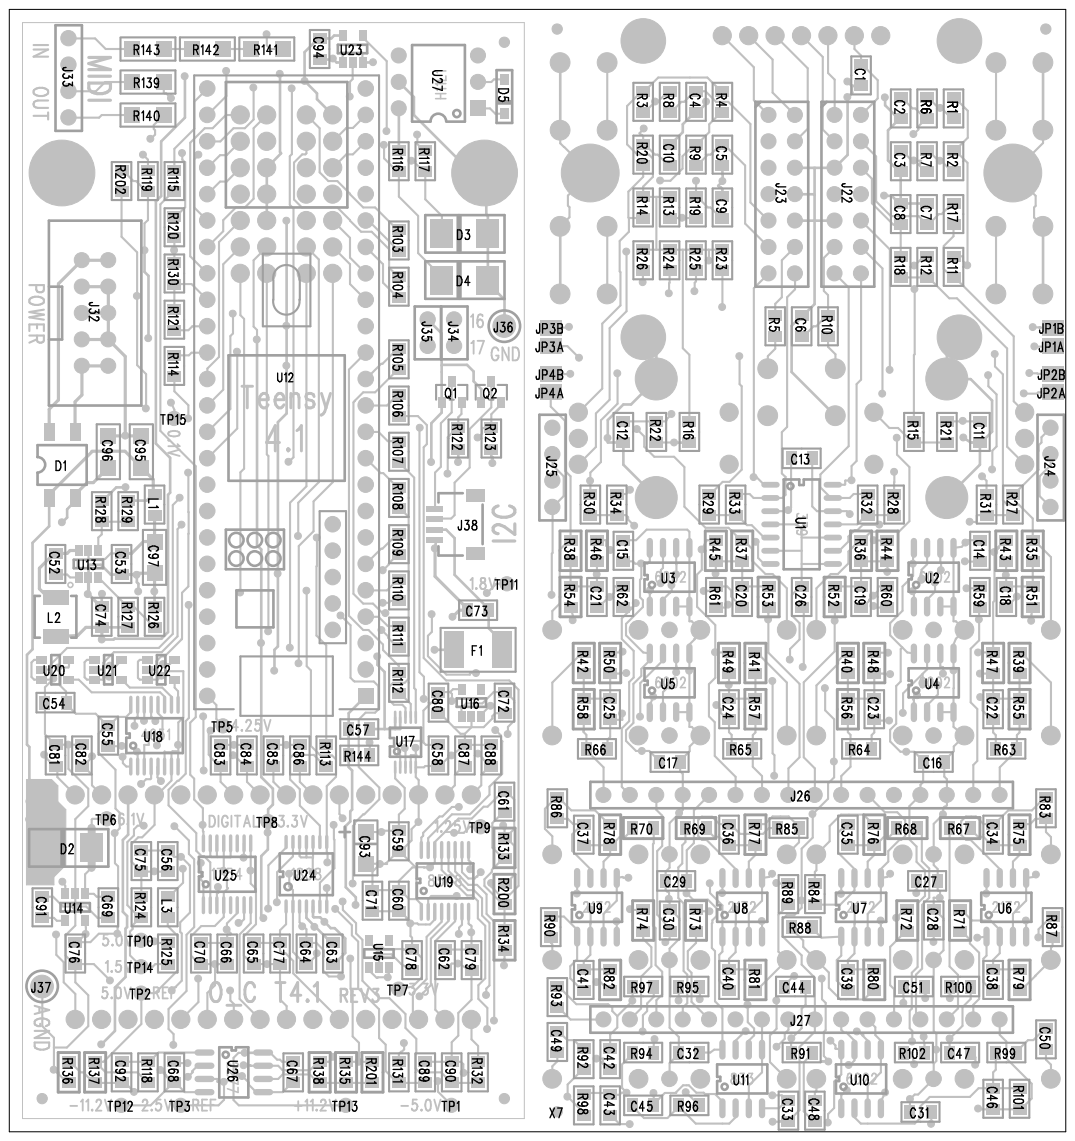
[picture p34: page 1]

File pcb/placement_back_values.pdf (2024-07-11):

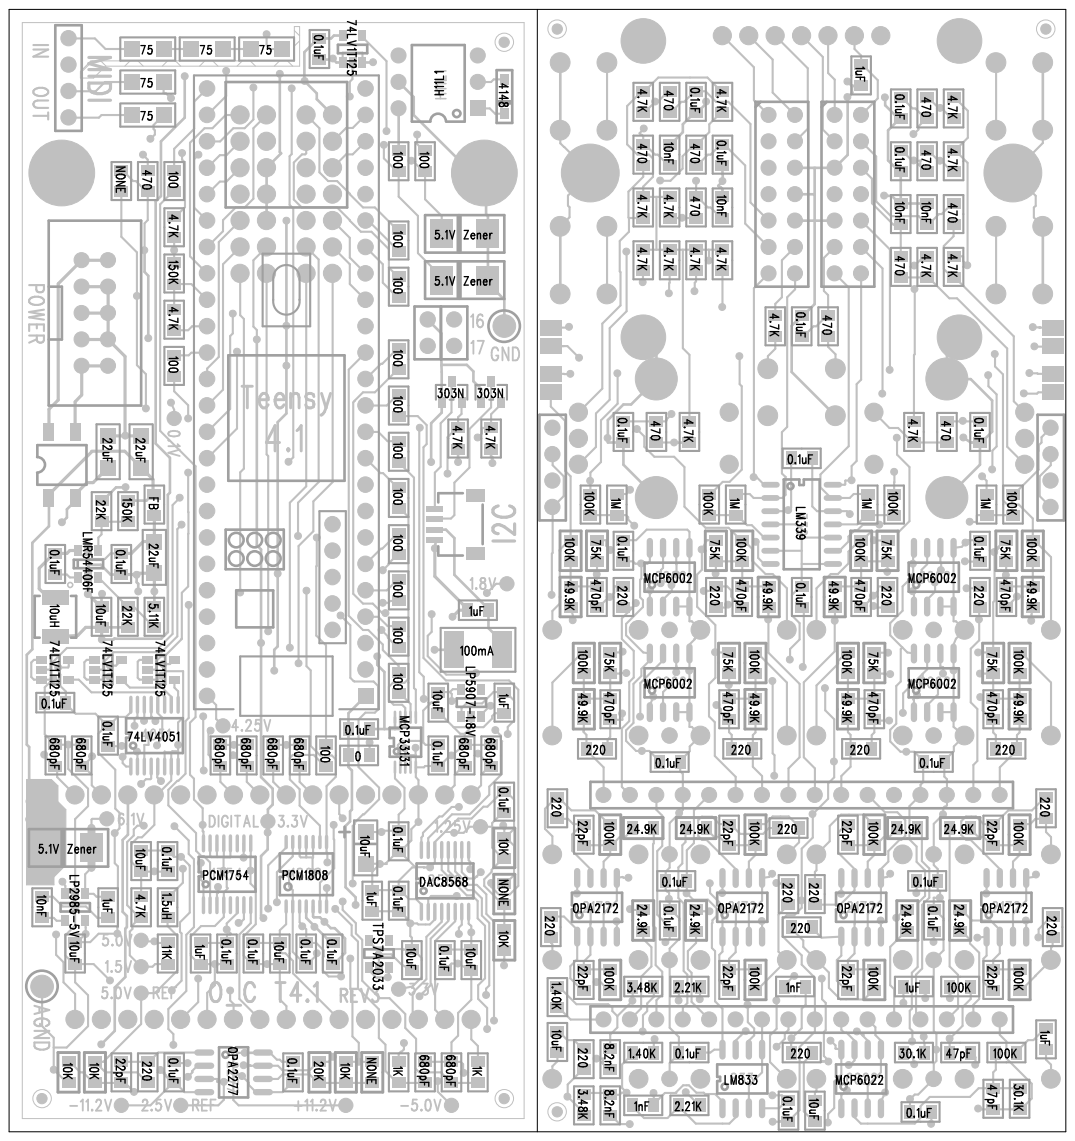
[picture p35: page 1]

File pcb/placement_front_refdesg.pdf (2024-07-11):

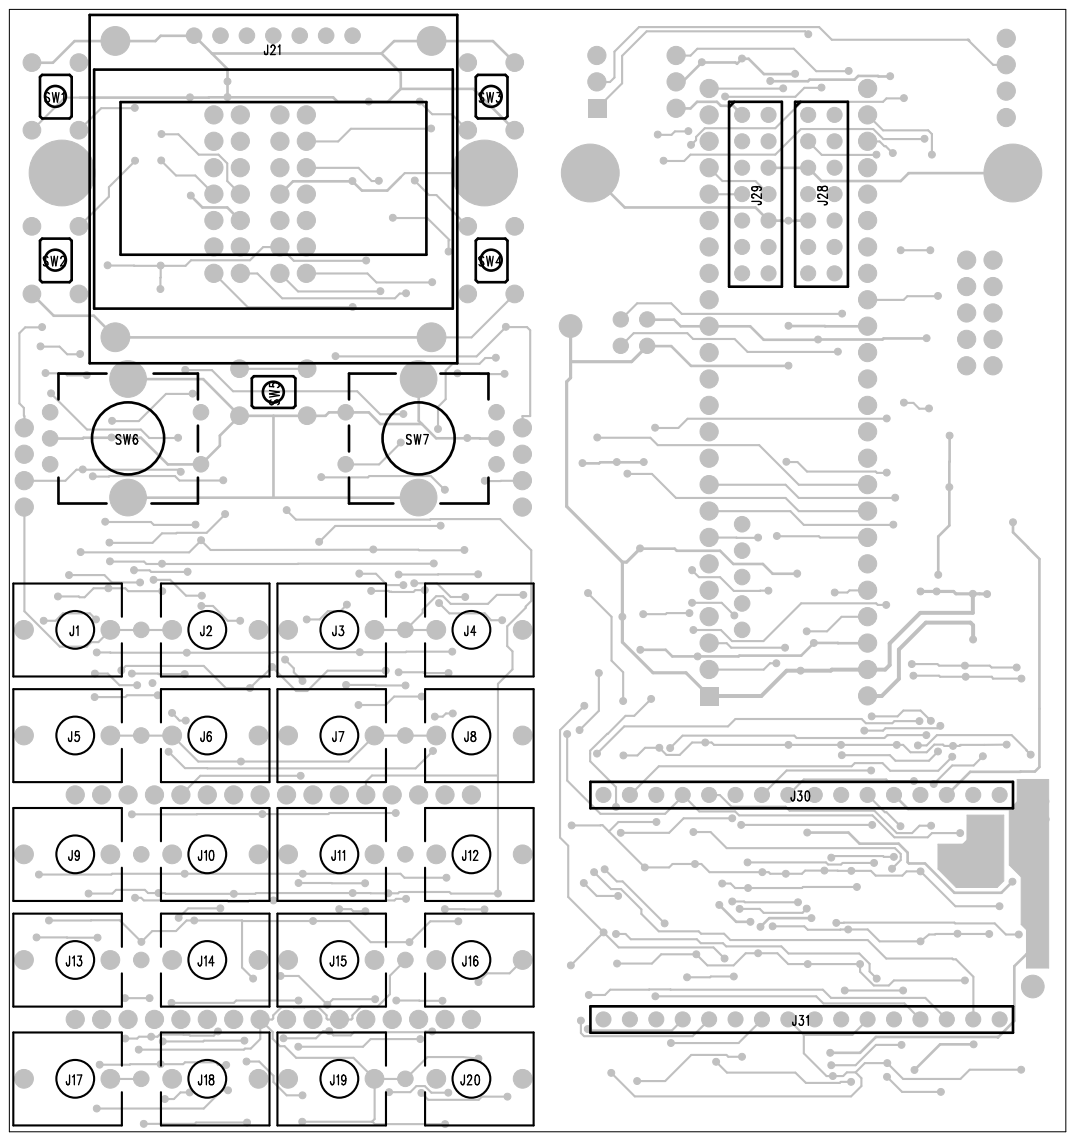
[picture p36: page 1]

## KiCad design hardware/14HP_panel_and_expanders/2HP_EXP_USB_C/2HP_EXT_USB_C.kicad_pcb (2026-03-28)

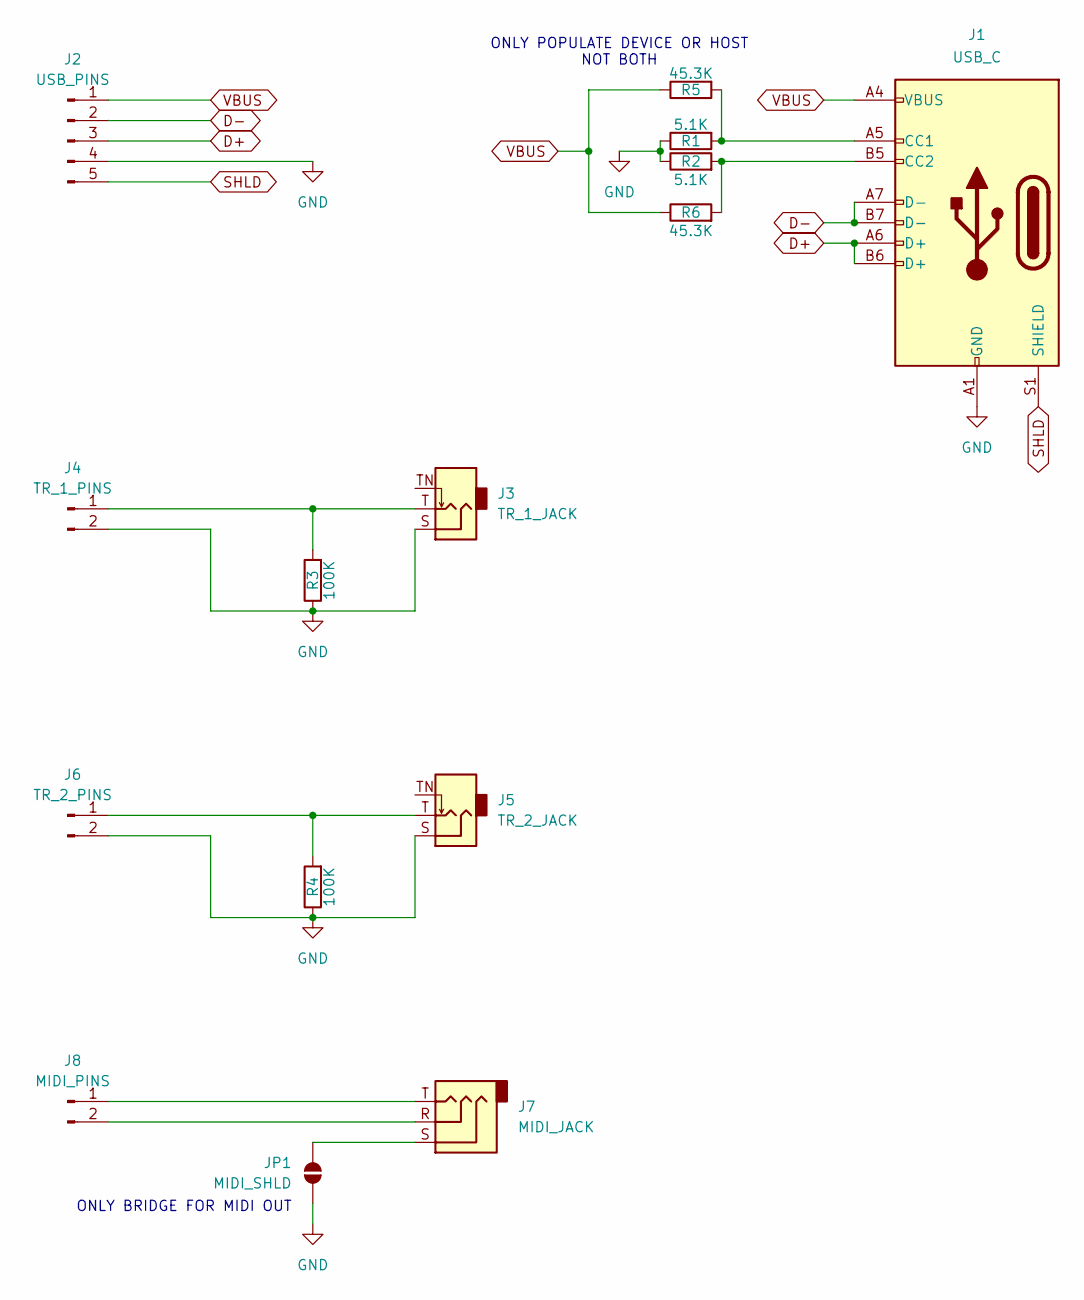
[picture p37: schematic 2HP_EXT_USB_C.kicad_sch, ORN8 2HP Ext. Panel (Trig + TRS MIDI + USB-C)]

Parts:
J1: USB_C; SparkFun USB-C Vertical
J2: USB_PINS; PinHeader_1x05_P2.54mm_Vertical
J3: TR_1_JACK; Jack_3.5mm_QingPu_WQP-PJ398SM_Vertical_CircularHoles
J4: TR_1_PINS; PinHeader_1x02_P2.54mm_Vertical
J5: TR_2_JACK; Jack_3.5mm_QingPu_WQP-PJ398SM_Vertical_CircularHoles
J6: TR_2_PINS; PinHeader_1x02_P2.54mm_Vertical
J7: MIDI_JACK; Jack_3.5mm_QingPu_WQP-PJ398SM_Vertical_CircularHoles
J8: MIDI_PINS; PinHeader_1x02_P2.54mm_Vertical
JP1: MIDI_SHLD; SolderJumper-2_P1.3mm_Open_TrianglePad1.0x1.5mm
R1, R2: 5.1K; R_0805_2012Metric_Pad1.20x1.40mm_HandSolder
R3, R4: 100K; R_0805_2012Metric_Pad1.20x1.40mm_HandSolder
R5, R6: 45.3K; R_0805_2012Metric_Pad1.20x1.40mm_HandSolder

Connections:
D+: J1.A6 (D+), J1.B6 (D+), J2.3
D-: J1.A7 (D-), J1.B7 (D-), J2.2
GND: J1.A1 (GND), J1.A12 (GND), J1.B1 (GND), J1.B12 (GND), J2.4, J3.S, J4.2, J5.S, J6.2, JP1.2 (B), R1.1, R2.1, R3.1, R4.1
unnamed: J1.A5 (CC1), R1.2, R5.2
unnamed: J1.B5 (CC2), R2.2, R6.2
unnamed: J3.T, J4.1, R3.2
unnamed: J5.T, J6.1, R4.2
unnamed: J7.T, J8.1
unnamed: J7.R, J8.2
unnamed: J7.S, JP1.1 (A)
SHLD: J1.S1 (SHIELD), J2.5
VBUS: J1.A4 (VBUS), J1.A9 (VBUS), J1.B4 (VBUS), J1.B9 (VBUS), J2.1, R5.1, R6.1

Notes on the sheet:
ONLY POPULATE DEVICE OR HOST NOT BOTH
ONLY BRIDGE FOR MIDI OUT

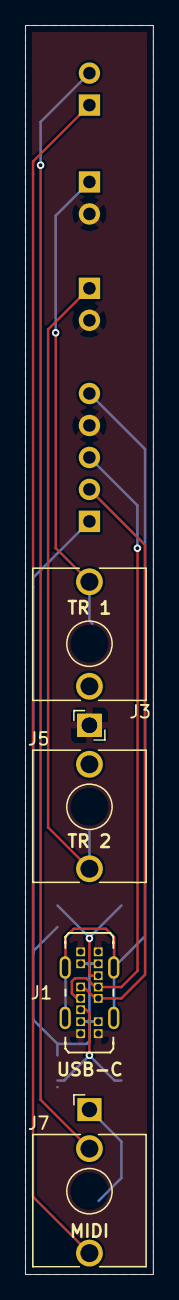
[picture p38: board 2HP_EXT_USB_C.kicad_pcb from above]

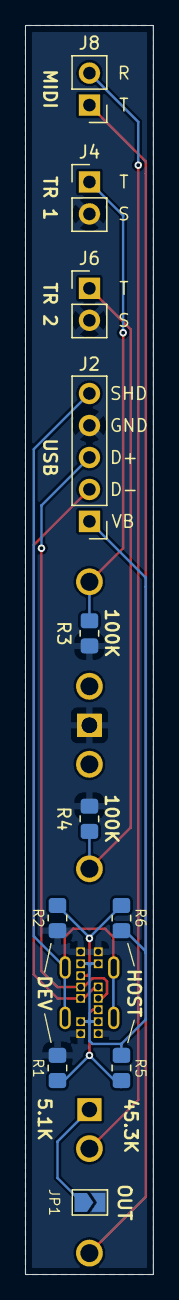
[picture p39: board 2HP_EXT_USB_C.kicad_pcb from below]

Board: 2 copper layers, 10.2 x 99.2 mm, 15 parts (11 on the bottom side), 12 nets.

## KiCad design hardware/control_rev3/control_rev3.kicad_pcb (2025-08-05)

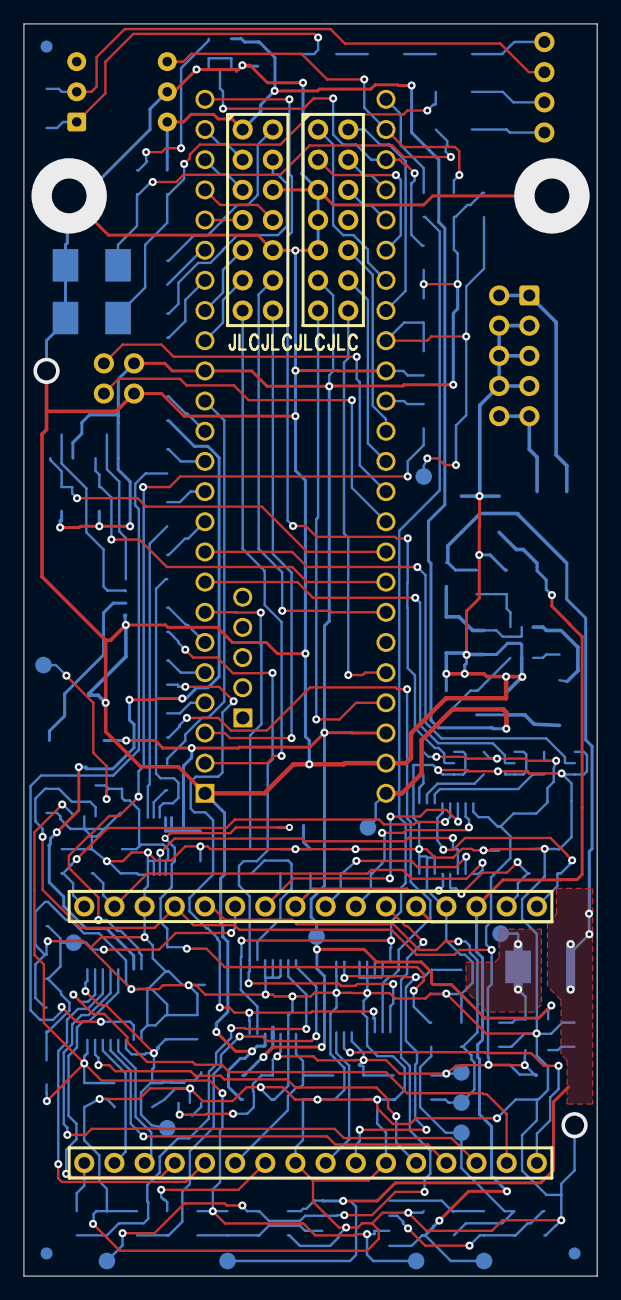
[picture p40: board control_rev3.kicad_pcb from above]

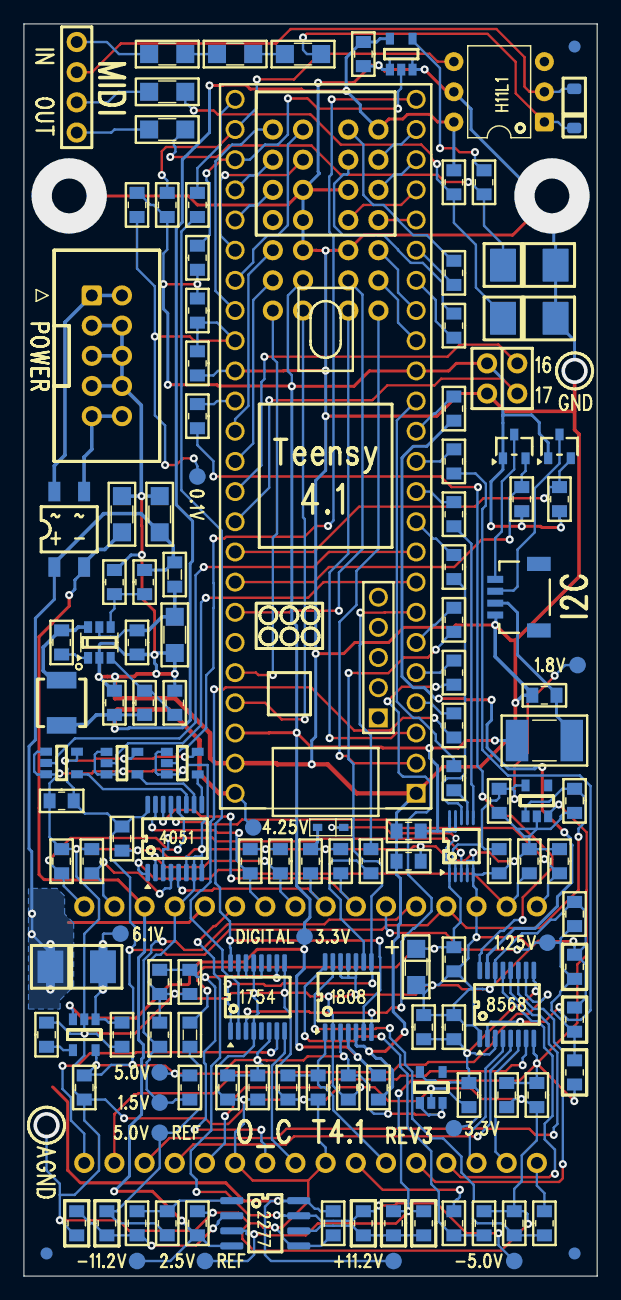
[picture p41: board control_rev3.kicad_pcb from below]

Board: 2 copper layers, 48.3 x 105.4 mm, 127 parts (123 on the bottom side), 122 nets.

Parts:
C52, C53, C54, C55, C56, C57, C58, C59, C60, C61, C62, C63, C64, C65, C66, C67, C68, C94: 0.1uF; C_0805_2012Metric_Pad1.18x1.45mm_HandSolder_rectpads
C69, C70, C71, C72, C73: 1uF; C_0805_2012Metric_Pad1.18x1.45mm_HandSolder_rectpads
C74, C75, C76, C77, C78, C79, C80: 10uF; C_0805_2012Metric_Pad1.18x1.45mm_HandSolder_rectpads
C81, C82, C83, C84, C85, C86, C87, C88, C89, C90: 680pF; C_0805_2012Metric_Pad1.18x1.45mm_HandSolder_rectpads
C91: 10nF; C_0805_2012Metric_Pad1.18x1.45mm_HandSolder_rectpads
C92: 22pF; C_0805_2012Metric_Pad1.18x1.45mm_HandSolder_rectpads
C93: 10uF Tantalum; C_1206_3216Metric_Pad1.33x1.80mm_HandSolder_rectpads
C95, C96, C97: 22uF; C_1206_3216Metric_Pad1.33x1.80mm_HandSolder_rectpads
D1: HD01-T; Diode_Bridge_reduced
D2: 5.1V 3W; D_SMB_Handsoldering_rectpads
D3, D4: 5.1V; D_SMB_Handsoldering_rectpads
D5: 1N4148W; D_SOD-123
D6: BZT52B5V1S; D_SOD-323F_rectpads
F1: 100mA; Fuse_1812_4532Metric_Pad1.30x3.40mm_HandSolder_rectpads
J28, J29: Conn_02x07; PinSocket_2x07_P2.54mm_Vertical_reduced
J30, J31: Conn_01x16; PinSocket_1x16_P2.54mm_Vertical_reduced
J32: Conn_02x05_Odd_Even; IDC-Header_2x05_P2.54mm_Vertical_reduced
J33: MIDI; PinHeader_1x04_P2.54mm_Vertical_reduced
J34: Conn_02x02_Odd_Even; PinHeader_2x02_P2.54mm_Vertical_symmetric
J38: QWIIC; JST_SMD_1.0mm-4
L1: 600Ω @100MHz; L_0805_2012Metric_rectpads
L2: 10uH; L_Abracon_ASPI-4030S_rectpads
L3: 1.5uH; L_0805_2012Metric_rectpads
Q1, Q2: FDV303N; SOT-23-3_rectpads
R103, R104, R105, R106, R107, R108, R109, R110, R111, R112, R113, R114, R115, R116, R117: 100Ω; R_0805_2012Metric_Pad1.20x1.40mm_HandSolder_rectpads
R118: 220; R_0805_2012Metric_Pad1.20x1.40mm_HandSolder_rectpads
R119: 470; R_0805_2012Metric_Pad1.20x1.40mm_HandSolder_rectpads
R120, R122, R123: 4.7K; R_0805_2012Metric_Pad1.20x1.40mm_HandSolder_rectpads
R121, R124: 4.7K 1%; R_0805_2012Metric_Pad1.20x1.40mm_HandSolder_rectpads
R125: 11K 1%; R_0805_2012Metric_Pad1.20x1.40mm_HandSolder_rectpads
R126: 5.11K 1%; R_0805_2012Metric_Pad1.20x1.40mm_HandSolder_rectpads
R127, R128: 22K 1%; R_0805_2012Metric_Pad1.20x1.40mm_HandSolder_rectpads
R129, R130: 150K 1%; R_0805_2012Metric_Pad1.20x1.40mm_HandSolder_rectpads
R131, R132: 1K; R_0805_2012Metric_Pad1.20x1.40mm_HandSolder_rectpads
R133, R134, R135, R136, R137: 10K 0.05%; R_0805_2012Metric_Pad1.20x1.40mm_HandSolder_rectpads
R138: 20K 0.05%; R_0805_2012Metric_Pad1.20x1.40mm_HandSolder_rectpads
R139, R140, R141, R142, R143: 75Ω ¼W; R_1206_3216Metric_Pad1.30x1.75mm_HandSolder_rectpads
R144: 0Ω; R_0805_2012Metric_Pad1.20x1.40mm_HandSolder_rectpads
R200, R201, R202: None; R_0805_2012Metric_Pad1.20x1.40mm_HandSolder_rectpads
U12: TEENSY41; Teensy41
U13: LMR54406F; SOT-23-6_rectpads
U14: LP2985A-5.0; SOT-23-5_reducedpads
U15: TPS7A2033; SOT-23-5_reducedpads
U16: LP5907-1.8; SOT-23-5_reducedpads
U17: MCP33131D; MSOP-10_3x3mm_P0.5mm_silkscreen+footprint
U18: 74LV4051; TSSOP-16_4.4x5mm_P0.65mm_silkscreen
U19: DAC8568; TSSOP-16_4.4x5mm_P0.65mm_silkscreen
U20, U21, U22, U23: 74LV1T125; SOT-23-5_reducedpads
U24: PCM1808; TSSOP-14_4.4x5mm_P0.65mm_silkscreen
U25: PCM1754; TSSOP-16_4.4x5mm_P0.65mm_silkscreen
U26: OPA2277; SOIC-8_3.9x4.9mm_P1.27mm_shiftedpads
U27: H11L1; DIP-6_W7.62mm

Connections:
+3V3: C57.1, C63.1, F1.2, J28.12, J34.1, Q1.1 (G), Q2.1 (G), R119.1, R120.1, R122.1, R123.1, R130.1, R202.1, U14.3 (ON/~OFF), U17.9 (SDI), U17.10 (DVIO), U24.4 (VDD)
+4V: C74.1, C94.1, J29.2, L2.2, R116.1, R127.1, U23.5 (VCC), U27.6
+5VA: C54.1, C55.1, C64.1, C66.1, C70.1, C72.1, C76.1, J30.4, R125.1, U14.5 (VOUT), U15.1 (IN), U15.3 (EN), U16.1 (IN), U18.16 (VCC), U20.5 (VCC), U21.5 (VCC), U22.5 (VCC), U24.3 (VCC), U25.6 (VCC)
+12VA: C67.1, C95.1, D1.1 (+), D2.1 (K), J30.12, L1.1, R129.1, U26.8 (V+)
-12VA: C68.2, C96.1, D1.2 (-), J30.14, U26.4 (V-)
/ADC_CS: R107.1, U12.9 (FlexIO2_11)
/ADC_MISO: R112.2, U12.12 (FlexIO2_1)
/ADC_MUX_A0: U12.7 (FlexIO2_17), U20.2 (A)
/ADC_MUX_A1: U12.6 (FlexIO2_10), U21.2 (A)
/ADC_MUX_A2: U12.32 (FlexIO2_12), U22.2 (A)
/ADC_SCK: R108.1, U12.8 (FlexIO2_16)
/DAC_CS: R106.1, U12.10 (SPI0_CS)
/DAC_MOSI: R105.1, U12.11 (SPI0_MOSI)
/DAC_SCK: R114.1, U12.13 (SPI0_SCK)
/DEBUG1: J34.2, U12.16
/DEBUG2: J34.4, U12.17
/ENC_L_A: J29.4, U12.31
/ENC_L_B: J29.6, U12.30
/ENC_L_SW: J29.12, U12.24
/ENC_R_A: J28.5, U12.37
/ENC_R_B: J28.3, U12.36
/ENC_R_SW: J29.10, U12.25
/HW_ID: R121.1, R130.2, R202.2, U12.41 (A17)
/I2C_SCL: Q1.2 (S), R122.2, U12.19 (SCL)
/I2C_SDA: Q2.2 (S), R123.2, U12.18 (SDA)
/I2S_BCLK: R109.1, U12.4 (I2S2_BCLK)
/I2S_DATA_ADC: R113.1, U12.5 (I2S2_IN2)
/I2S_DATA_DAC: R111.1, U12.2 (I2S2_OUT)
/I2S_LRCLK: R110.1, U12.3 (I2S2_LRCLK)
/I2S_MCLK: R115.1, U12.33 (I2S2_MCLK)
/MIDI_IN: R119.2, U12.34 (Serial8_RX), U27.4
/MIDI_OUT: R120.2, U12.35 (Serial8_TX), U23.2 (A)
/OLED_CS: J28.1, U12.40
/OLED_DC: J28.2, U12.39
/OLED_MOSI: R104.1, U12.26 (SPI1_MOSI)
/OLED_RST: J28.4, U12.38
/OLED_SCK: R103.1, U12.27 (SPI1_SCK)
/SW_A: J29.7, U12.29
/SW_B: J28.9, U12.14
/SW_X: J29.8, U12.28
/SW_Y: J28.11, U12.15
/SW_ZAP: J29.11, U12.20
/TR1: J29.14, U12.0
/TR2: J29.13, U12.1
/TR3: J28.14, U12.23
/TR4: J28.13, U12.22
Earth: C53.2, C57.2, C63.2, C73.2, C74.2, C94.2, C95.2, C96.2, C97.2, D3.2 (A), D4.2 (A), J28.6, J28.8, J28.10, J29.5, J29.9, J32.3, J32.4, J32.5, J32.6, J32.7, J32.8, J34.3, J38.1, R121.2, R126.2, R128.2, R144.1, U13.2 (GND), U23.1 (~OE), U23.3 (GND), U24.5 (DGND), U27.5
GND: C54.2, C55.2, C56.2, C58.2, C59.2, C60.2, C61.2, C62.2, C64.2, C65.2, C66.2, C67.2, C68.1, C69.2, C70.2, C71.2, C72.2, C75.2, C76.2, C77.2, C78.2, C79.2, C80.2, C81.2, C82.2, C83.2, C84.2, C85.2, C86.2, C87.2, C88.2, C89.2, C90.2, C91.2, C93.2, D6.2 (A), J30.3, J30.13, J31.8, J31.11, R124.2, R133.2, R136.1, R144.2, R200.2, U14.2 (GND), U15.2 (GND), U16.2 (GND), U17.4 (AIN-), U17.5 (GND), U18.6 (~E), U18.7 (VEE), U18.8 (GND), U19.1 (~LDAC), U19.14 (GND), U20.1 (~OE), U20.3 (GND), U21.1 (~OE), U21.3 (GND), U22.1 (~OE), U22.3 (GND), U24.2 (AGND), U24.10 (MD0), U24.11 (MD1), U24.12 (FMT), U25.4 (DGND), U25.9 (AGND), U25.12 (TEST), U25.13 (DEMP), U25.14 (MUTE), U25.15 (FMT), U26.5 (+)
unnamed: C92.2, R118.1, U26.1
unnamed: C69.1, D2.2 (A), U14.1 (VIN)
unnamed: D3.1 (K), R117.2, R140.1
unnamed: D4.1 (K), R116.2, R139.1
unnamed: D5.2 (A), J33.2, U27.2
unnamed: D5.1 (K), R141.1, U27.1
unnamed: C59.1, C93.1, D6.1 (K), L3.2, U17.1 (VREF)
unnamed: J29.1, R103.2
unnamed: J29.3, R104.2
unnamed: C88.1, J30.1, U18.13 (A0)
unnamed: C87.1, J30.2, U18.1 (A4)
unnamed: J30.5, R124.1, R125.2
unnamed: C61.1, J30.6, R133.1, R134.2, R200.1
unnamed: C86.1, J30.7, U18.14 (A1)
unnamed: C85.1, J30.8, U18.5 (A5)
unnamed: C84.1, J30.9, U18.2 (A6)
unnamed: C83.1, J30.10, U18.15 (A2)
unnamed: J30.11, R138.2, U26.7
unnamed: C82.1, J30.15, U18.4 (A7)
unnamed: C81.1, J30.16, U18.12 (A3)
unnamed: J31.1, R132.2
unnamed: J31.2, U19.6 (VOUTE)
unnamed: J31.3, U19.4 (VOUTA)
unnamed: J31.4, U19.13 (VOUTB)
unnamed: J31.5, U19.11 (VOUTF)
unnamed: C65.1, C77.1, J31.6, U24.1 (VREF)
unnamed: J31.7, R131.2
unnamed: J31.9, U25.8 (VOUTR)
unnamed: C56.1, C75.1, J31.10, U25.10 (VCCM)
unnamed: J31.12, U19.7 (VOUTG)
unnamed: J31.13, U19.5 (VOUTC)
unnamed: J31.14, U19.12 (VOUTD)
unnamed: J31.15, U19.10 (VOUTH)
unnamed: J31.16, U25.7 (VOUTL)
unnamed: D1.3, J32.1, J32.2
unnamed: D1.4, J32.9, J32.10
unnamed: J33.1, R143.2
unnamed: J33.3, R139.2
unnamed: J33.4, R140.2
unnamed: C73.1, F1.1, J38.2
unnamed: J38.3, Q2.3 (D)
unnamed: J38.4, Q1.3 (D)
unnamed: L3.1, R118.2, R137.2
unnamed: R141.2, R142.1
unnamed: R142.2, R143.1
unnamed: C52.1, U13.1 (CB)
unnamed: R128.1, R129.2, U13.4 (EN)
unnamed: R126.1, R127.2, U13.3 (FB)
unnamed: C52.2, L2.1, U13.6 (SW)
unnamed: C53.1, C97.1, L1.2, U13.5 (VIN)
unnamed: C91.1, U14.4 (BP)
unnamed: C60.1, C71.1, C78.1, U15.5 (OUT), U19.3 (AVDD), U19.9 (~CLR)
unnamed: C62.1, C79.1, R134.1, R135.1, R201.1, U16.3 (EN), U19.8 (VREF), U26.3 (+)
unnamed: C58.1, C80.1, U16.5 (OUT), U17.2 (AVDD)
unnamed: U17.3 (AIN+), U18.3 (A)
unnamed: R107.2, U17.6 (CNVST)
unnamed: R108.2, U17.8 (SCLK)
unnamed: R112.1, U17.7 (SDO)
unnamed: U18.11 (S0), U20.4 (Y)
unnamed: U18.10 (S1), U21.4 (Y)
unnamed: U18.9 (S2), U22.4 (Y)
unnamed: R105.2, U19.15 (DIN)
unnamed: R114.2, U19.16 (SCLK)
unnamed: R106.2, U19.2 (~SYNC)
unnamed: R117.1, U23.4 (Y)
unnamed: R109.2, U24.8 (BCK), U25.1 (BCK)
unnamed: R113.2, U24.9 (DOUT)
unnamed: R110.2, U24.7 (LRCK), U25.3 (LRCK)
unnamed: R115.2, U24.6 (SCKI), U25.16 (SCK)
unnamed: C90.1, R132.1, U24.13 (VINL)
unnamed: C89.1, R131.1, U24.14 (VINR)
unnamed: R111.2, U25.2 (DATA)
unnamed: C92.1, R136.2, R137.1, U26.2 (-)
unnamed: R135.2, R138.1, R201.2, U26.6 (-)

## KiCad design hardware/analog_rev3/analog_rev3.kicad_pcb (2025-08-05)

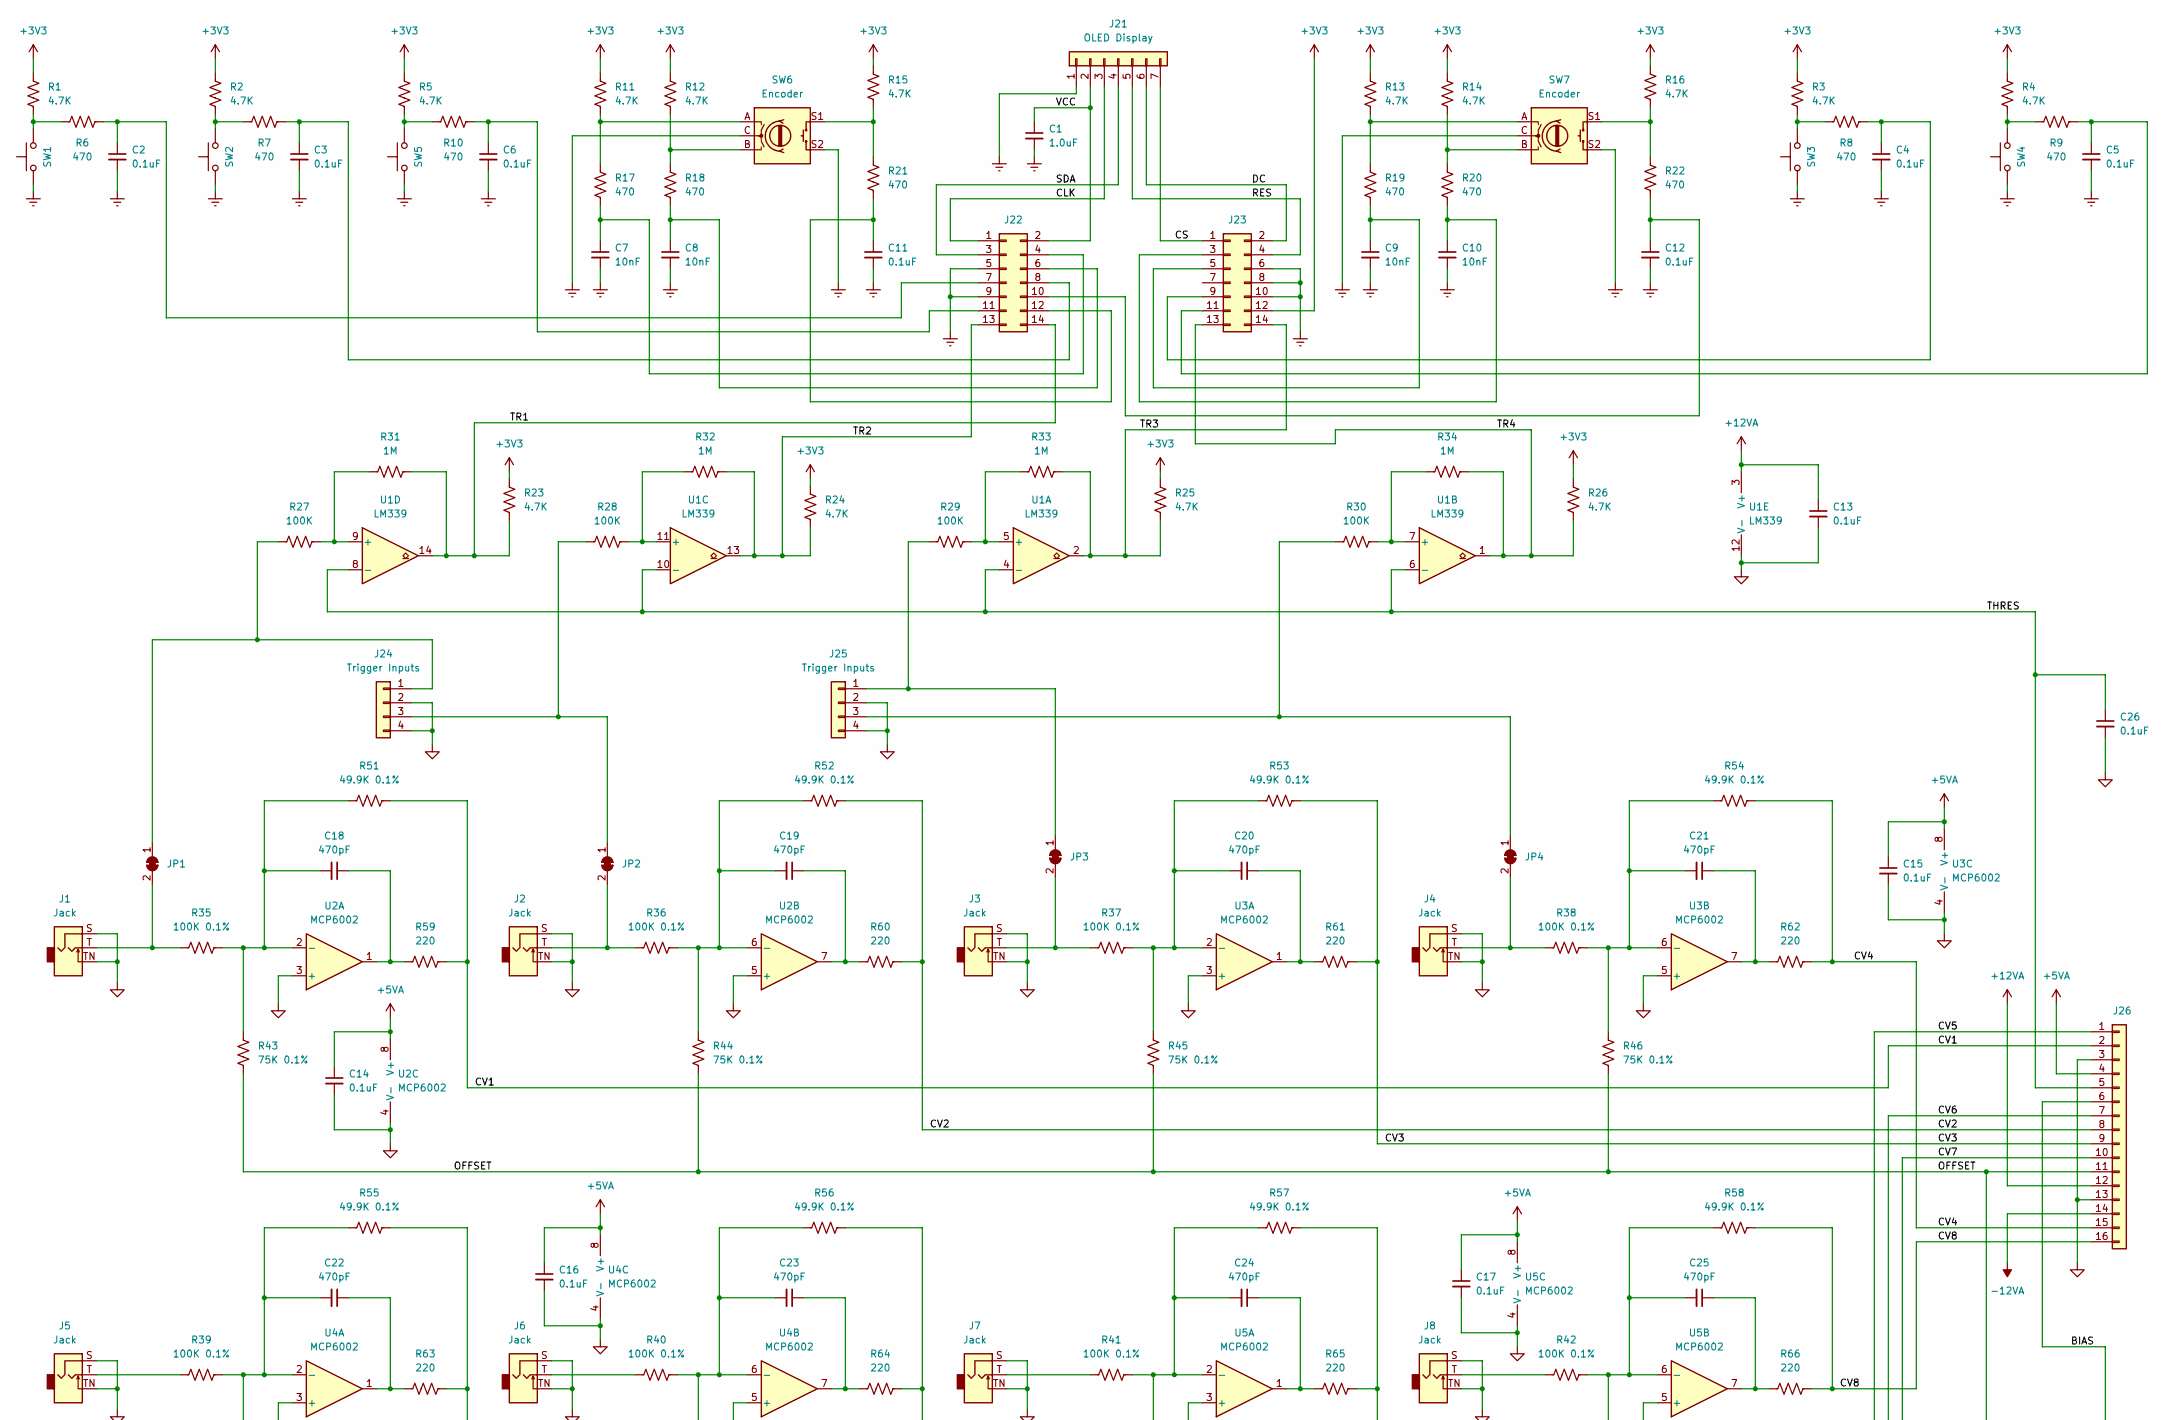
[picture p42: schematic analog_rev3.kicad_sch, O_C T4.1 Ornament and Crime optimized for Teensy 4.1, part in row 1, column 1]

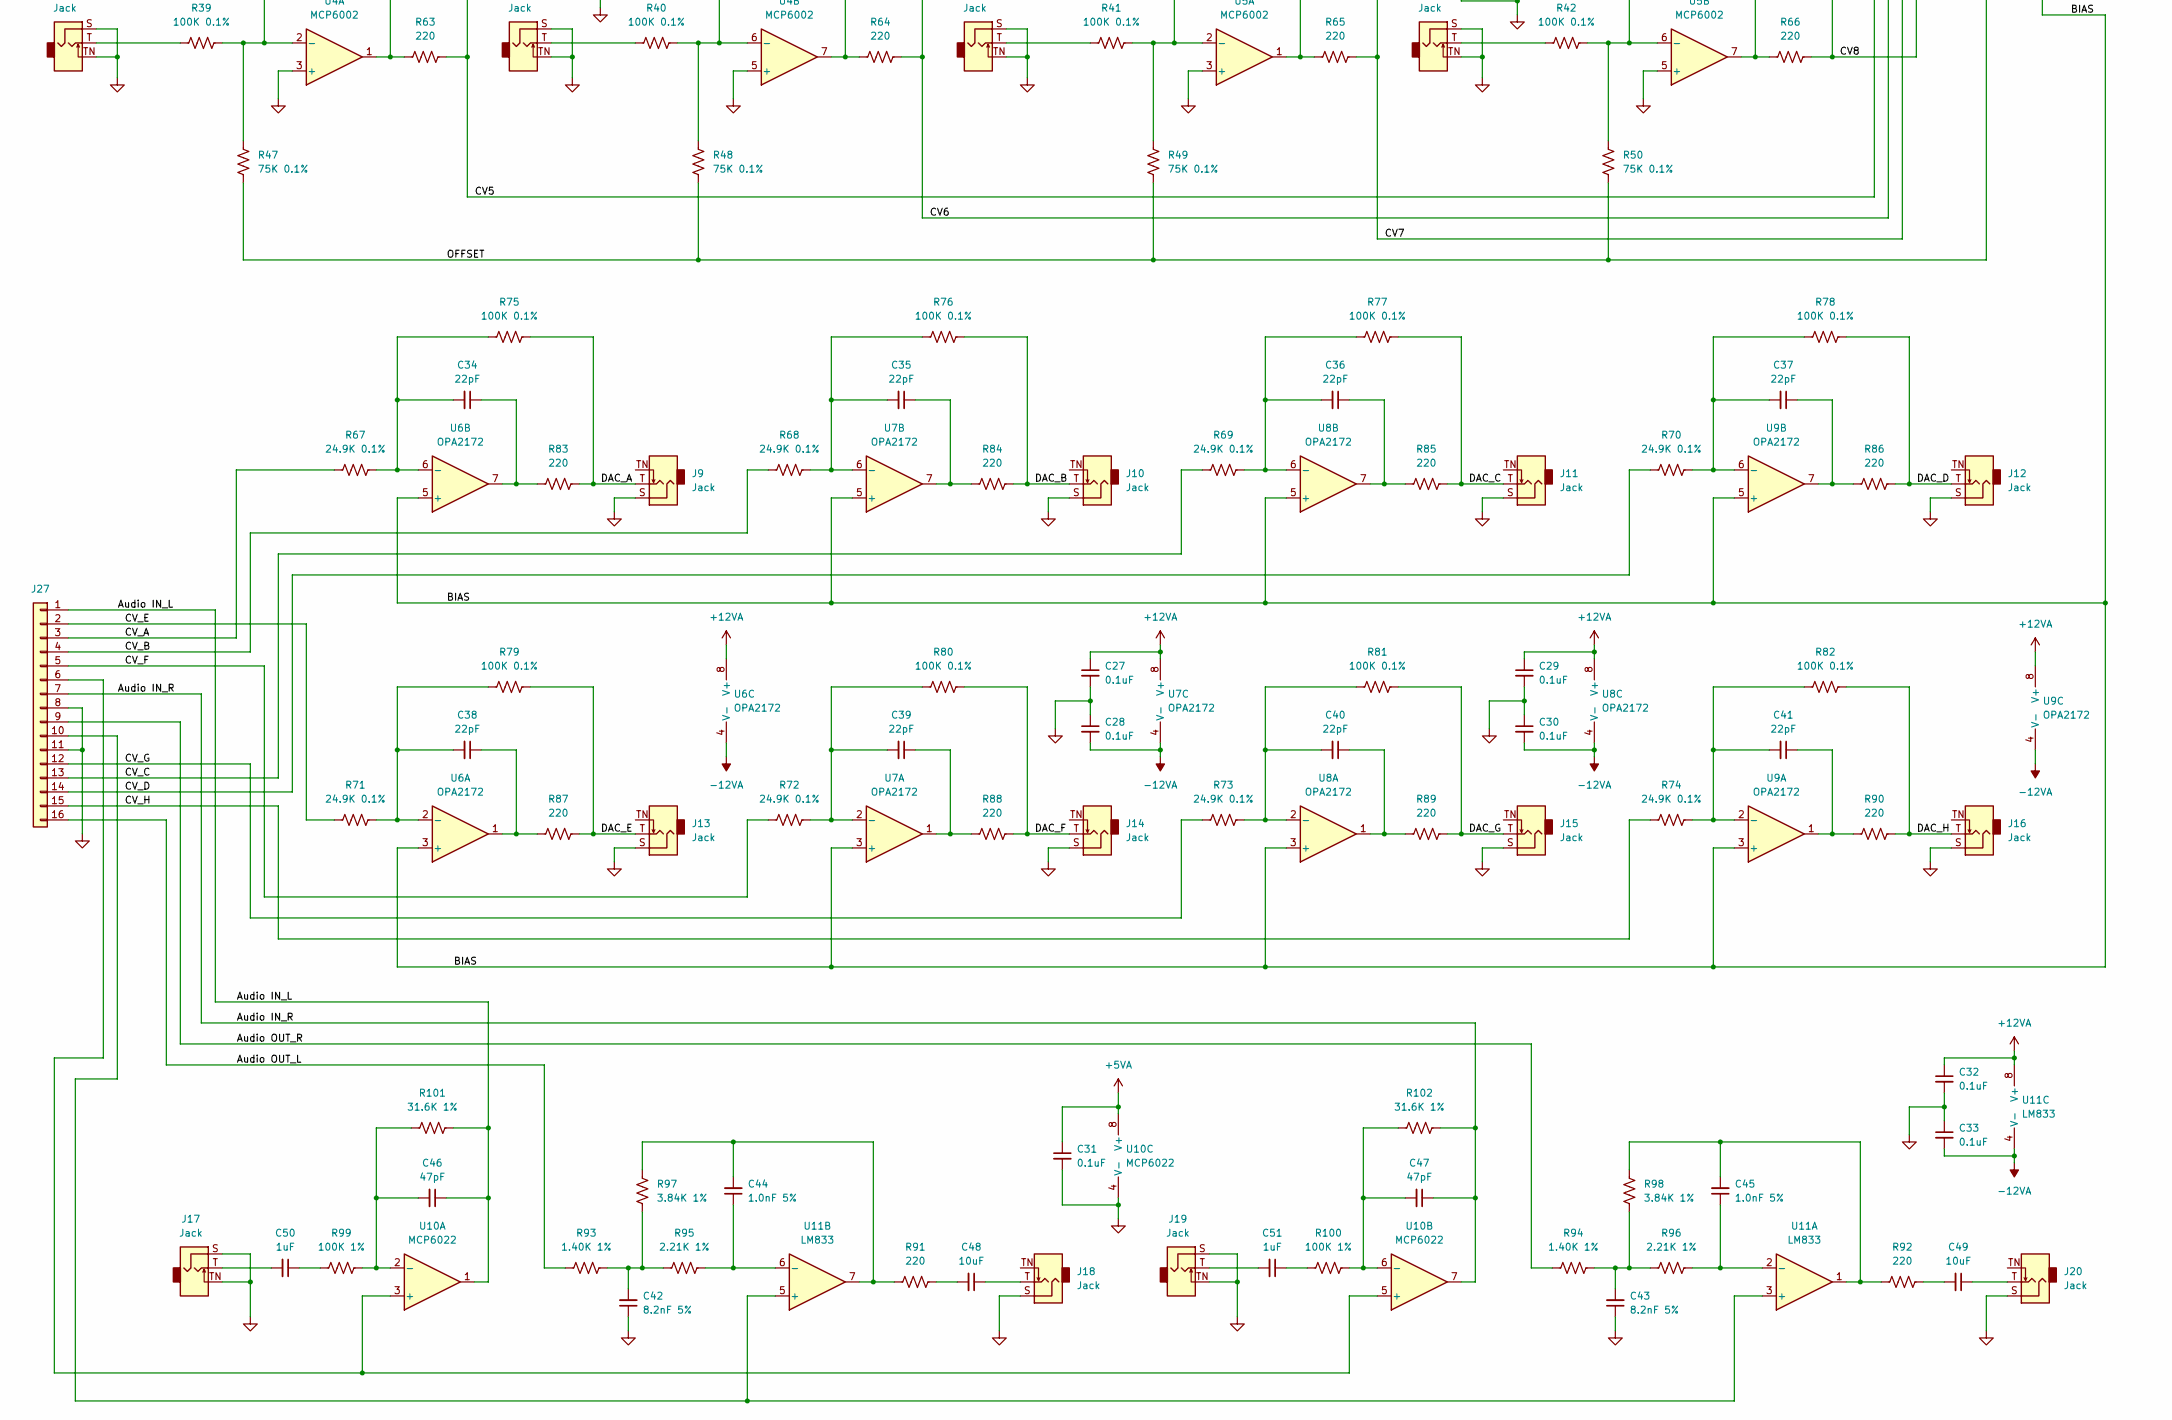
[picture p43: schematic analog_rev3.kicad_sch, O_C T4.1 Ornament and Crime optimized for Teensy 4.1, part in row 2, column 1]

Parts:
C1: 1.0uF; C_0805_2012Metric_Pad1.18x1.45mm_HandSolder_rectpads
C2, C3, C4, C5, C6, C11, C12, C13, C14, C15, C16, C17, C26, C27, C28, C29, C30, C31, C32, C33: 0.1uF; C_0805_2012Metric_Pad1.18x1.45mm_HandSolder_rectpads
C7, C8, C9, C10: 10nF; C_0805_2012Metric_Pad1.18x1.45mm_HandSolder_rectpads
C18, C19, C20, C21, C22, C23, C24, C25: 470pF; C_0805_2012Metric_Pad1.18x1.45mm_HandSolder_rectpads
C34, C35, C36, C37, C38, C39, C40, C41: 22pF; C_0805_2012Metric_Pad1.18x1.45mm_HandSolder_rectpads
C42, C43: 8.2nF 5%; C_0805_2012Metric_Pad1.18x1.45mm_HandSolder_rectpads
C44, C45: 1.0nF 5%; C_0805_2012Metric_Pad1.18x1.45mm_HandSolder_rectpads
C46, C47: 47pF; C_0805_2012Metric_Pad1.18x1.45mm_HandSolder_rectpads
C48, C49: 10uF; C_0805_2012Metric_Pad1.18x1.45mm_HandSolder_rectpads
C50, C51: 1uF; C_0805_2012Metric_Pad1.18x1.45mm_HandSolder_rectpads
J1, J2, J3, J4, J5, J6, J7, J8, J9, J10, J11, J12, J13, J14, J15, J16, J17, J18, J19, J20: Jack; Jack_3.5mm_QingPu_WQP-PJ398SM_Vertical_CircularHoles_reduced
J21: OLED Display; PinHeader_1x07_P2.54mm_Vertical
J22, J23: Conn_02x07; PinHeader_2x07_P2.54mm_Vertical_reduced
J24, J25: Trigger Inputs; PinHeader_1x04_P2.54mm_Vertical_reduced
J26, J27: Conn_01x16; PinHeader_1x16_P2.54mm_Vertical_reduced
JP1, JP2, JP3, JP4: SolderJumper_2_Bridged; SolderJumper-2_P1.3mm_Bridged_Pad1.0x1.5mm_reduced
R1, R2, R3, R4, R5, R11, R12, R13, R14, R15, R16, R23, R24, R25, R26: 4.7K; R_0805_2012Metric_Pad1.20x1.40mm_HandSolder_rectpads
R6, R7, R8, R9, R10, R17, R18, R19, R20, R21, R22: 470; R_0805_2012Metric_Pad1.20x1.40mm_HandSolder_rectpads
R27, R28, R29, R30: 100K; R_0805_2012Metric_Pad1.20x1.40mm_HandSolder_rectpads
R31, R32, R33, R34: 1M; R_0805_2012Metric_Pad1.20x1.40mm_HandSolder_rectpads
R35, R36, R37, R38, R39, R40, R41, R42, R75, R76, R77, R78, R79, R80, R81, R82: 100K 0.1%; R_0805_2012Metric_Pad1.20x1.40mm_HandSolder_rectpads
R43, R44, R45, R46, R47, R48, R49, R50: 75K 0.1%; R_0805_2012Metric_Pad1.20x1.40mm_HandSolder_rectpads
R51, R52, R53, R54, R55, R56, R57, R58: 49.9K 0.1%; R_0805_2012Metric_Pad1.20x1.40mm_HandSolder_rectpads
R59, R60, R61, R62, R63, R64, R65, R66, R83, R84, R85, R86, R87, R88, R89, R90, R91, R92: 220; R_0805_2012Metric_Pad1.20x1.40mm_HandSolder_rectpads
R67, R68, R69, R70, R71, R72, R73, R74: 24.9K 0.1%; R_0805_2012Metric_Pad1.20x1.40mm_HandSolder_rectpads
R93, R94: 1.40K 1%; R_0805_2012Metric_Pad1.20x1.40mm_HandSolder_rectpads
R95, R96: 2.21K 1%; R_0805_2012Metric_Pad1.20x1.40mm_HandSolder_rectpads
R97, R98: 3.84K 1%; R_0805_2012Metric_Pad1.20x1.40mm_HandSolder_rectpads
R99, R100: 100K 1%; R_0805_2012Metric_Pad1.20x1.40mm_HandSolder_rectpads
R101, R102: 31.6K 1%; R_0805_2012Metric_Pad1.20x1.40mm_HandSolder_rectpads
SW1, SW2, SW3, SW4, SW5: SW_Push; SW_PUSH_6mm
SW6, SW7: Encoder; RotaryEncoder_Alps_EC11E-Switch_Vertical_H20mm_CircularMoun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
U1: LM339; SOIC-14_3.9x8.7mm_P1.27mm_shiftedpads
U2, U3, U4, U5: MCP6002; SOIC-8_3.9x4.9mm_P1.27mm_shiftedpads
U6, U7, U8, U9: OPA2172; SOIC-8_3.9x4.9mm_P1.27mm_shiftedpads
U10: MCP6022; SOIC-8_3.9x4.9mm_P1.27mm_shiftedpads
U11: LM833; SOIC-8_3.9x4.9mm_P1.27mm_shiftedpads

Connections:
+3V3: J23.12, R1.1, R2.1, R3.1, R4.1, R5.1, R11.1, R12.1, R13.1, R14.1, R15.1, R16.1, R23.1, R24.1, R25.1, R26.1
+5VA: C14.1, C15.1, C16.1, C17.1, C31.1, J26.4, U2.8 (V+), U3.8 (V+), U4.8 (V+), U5.8 (V+), U10.8 (V+)
+12VA: C13.1, C27.1, C29.1, C32.1, J26.12, U1.3 (V+), U6.8 (V+), U7.8 (V+), U8.8 (V+), U9.8 (V+), U11.8 (V+)
-12VA: C28.2, C30.2, C33.2, J26.14, U6.4 (V-), U7.4 (V-), U8.4 (V-), U9.4 (V-), U11.4 (V-)
/Audio IN_L: C46.1, J27.1, R101.2, U10.1
/Audio IN_R: C47.1, J27.7, R102.2, U10.7
/Audio OUT_L: J27.16, R93.1
/Audio OUT_R: J27.9, R94.1
/BIAS: J26.6, U6.3 (+), U6.5 (+), U7.3 (+), U7.5 (+), U8.3 (+), U8.5 (+), U9.3 (+), U9.5 (+)
/CLK: J21.3, J22.1
/CS: J21.7, J23.1
/CV1: J26.2, R51.2, R59.2
/CV2: J26.8, R52.2, R60.2
/CV3: J26.9, R53.2, R61.2
/CV4: J26.15, R54.2, R62.2
/CV5: J26.1, R55.2, R63.2
/CV6: J26.7, R56.2, R64.2
/CV7: J26.10, R57.2, R65.2
/CV8: J26.16, R58.2, R66.2
/CV_A: J27.3, R67.1
/CV_B: J27.4, R68.1
/CV_C: J27.13, R69.1
/CV_D: J27.14, R70.1
/CV_E: J27.2, R71.1
/CV_F: J27.5, R72.1
/CV_G: J27.12, R73.1
/CV_H: J27.15, R74.1
/DAC_A: J9.T, R75.2, R83.2
/DAC_B: J10.T, R76.2, R84.2
/DAC_C: J11.T, R77.2, R85.2
/DAC_D: J12.T, R78.2, R86.2
/DAC_E: J13.T, R79.2, R87.2
/DAC_F: J14.T, R80.2, R88.2
/DAC_G: J15.T, R81.2, R89.2
/DAC_H: J16.T, R82.2, R90.2
/DC: J21.6, J23.2
/OFFSET: J26.11, R43.2, R44.2, R45.2, R46.2, R47.2, R48.2, R49.2, R50.2
/RES: J21.5, J23.4
/SDA: J21.4, J22.3
/THRES: C26.1, J26.5, U1.4 (-), U1.6 (-), U1.8 (-), U1.10 (-)
/TR1: J22.14, R23.2, R31.2, U1.14
/TR2: J22.13, R24.2, R32.2, U1.13
/TR3: J23.14, R25.2, R33.2, U1.2
/TR4: J23.13, R26.2, R34.2, U1.1
/VCC: C1.1, J21.2, J22.2
Earth: C1.2, C2.2, C3.2, C4.2, C5.2, C6.2, C7.2, C8.2, C9.2, C10.2, C11.2, C12.2, J21.1, J22.5, J22.9, J23.6, J23.8, J23.10, SW1.1, SW2.1, SW3.1, SW4.1, SW5.1, SW6.C, SW6.MP, SW6.S2, SW7.C, SW7.MP, SW7.S2
GND: C13.2, C14.2, C15.2, C16.2, C17.2, C26.2, C27.2, C28.1, C29.2, C30.1, C31.2, C32.2, C33.1, C42.1, C43.1, J1.S, J1.TN, J2.S, J2.TN, J3.S, J3.TN, J4.S, J4.TN, J5.S, J5.TN, J6.S, J6.TN, J7.S, J7.TN, J8.S, J8.TN, J9.S, J10.S, J11.S, J12.S, J13.S, J14.S, J15.S, J16.S, J17.S, J17.TN, J18.S, J19.S, J19.TN, J20.S, J24.2, J24.4, J25.2, J25.4, J26.3, J26.13, J27.8, J27.11, U1.12 (V-), U2.3 (+), U2.4 (V-), U2.5 (+), U3.3 (+), U3.4 (V-), U3.5 (+), U4.3 (+), U4.4 (V-), U4.5 (+), U5.3 (+), U5.4 (V-), U5.5 (+), U10.4 (V-)
unnamed: C18.1, R59.1, U2.1
unnamed: C19.1, R60.1, U2.7
unnamed: C20.1, R61.1, U3.1
unnamed: C21.1, R62.1, U3.7
unnamed: C22.1, R63.1, U4.1
unnamed: C23.1, R64.1, U4.7
unnamed: C24.1, R65.1, U5.1
unnamed: C25.1, R66.1, U5.7
unnamed: C34.1, R83.1, U6.7
unnamed: C35.1, R84.1, U7.7
unnamed: C36.1, R85.1, U8.7
unnamed: C37.1, R86.1, U9.7
unnamed: C38.1, R87.1, U6.1
unnamed: C39.1, R88.1, U7.1
unnamed: C40.1, R89.1, U8.1
unnamed: C41.1, R90.1, U9.1
unnamed: C42.2, R93.2, R95.1, R97.2
unnamed: C43.2, R94.2, R96.1, R98.2
unnamed: C44.2, R91.1, R97.1, U11.7
unnamed: C45.2, R92.1, R98.1, U11.1
unnamed: C48.1, J18.T
unnamed: C48.2, R91.2
unnamed: C49.1, J20.T
unnamed: C49.2, R92.2
unnamed: C50.1, R99.1
unnamed: C50.2, J17.T
unnamed: C51.1, R100.1
unnamed: C51.2, J19.T
unnamed: J5.T, R39.1
unnamed: J6.T, R40.1
unnamed: J7.T, R41.1
unnamed: J8.T, R42.1
unnamed: C7.1, J22.4, R17.2
unnamed: C8.1, J22.6, R18.2
unnamed: C2.1, J22.7, R6.1
unnamed: C3.1, J22.8, R7.1
unnamed: C12.1, J22.10, R22.2
unnamed: C6.1, J22.11, R10.1
unnamed: C11.1, J22.12, R21.2
unnamed: C10.1, J23.3, R20.2
unnamed: C9.1, J23.5, R19.2
unnamed: C4.1, J23.9, R8.1
unnamed: C5.1, J23.11, R9.1
unnamed: J24.1, JP1.1 (A), R27.1
unnamed: J24.3, JP2.1 (A), R28.1
unnamed: J25.1, JP3.1 (A), R29.1
unnamed: J25.3, JP4.1 (A), R30.1
unnamed: J27.6, U10.3 (+), U10.5 (+)
unnamed: J27.10, U11.3 (+), U11.5 (+)
unnamed: J1.T, JP1.2 (B), R35.1
unnamed: J2.T, JP2.2 (B), R36.1
unnamed: J3.T, JP3.2 (B), R37.1
unnamed: J4.T, JP4.2 (B), R38.1
unnamed: R1.2, R6.2, SW1.2
unnamed: R2.2, R7.2, SW2.2
unnamed: R3.2, R8.2, SW3.2
unnamed: R4.2, R9.2, SW4.2
unnamed: R5.2, R10.2, SW5.2
unnamed: R11.2, R17.1, SW6.A
unnamed: R12.2, R18.1, SW6.B
unnamed: R13.2, R19.1, SW7.A
unnamed: R14.2, R20.1, SW7.B
unnamed: R15.2, R21.1, SW6.S1
unnamed: R16.2, R22.1, SW7.S1
unnamed: R29.2, R33.1, U1.5 (+)
unnamed: R30.2, R34.1, U1.7 (+)
unnamed: R28.2, R32.1, U1.11 (+)
unnamed: R27.2, R31.1, U1.9 (+)
unnamed: C18.2, R35.2, R43.1, R51.1, U2.2 (-)
unnamed: C19.2, R36.2, R44.1, R52.1, U2.6 (-)
unnamed: C20.2, R37.2, R45.1, R53.1, U3.2 (-)
unnamed: C21.2, R38.2, R46.1, R54.1, U3.6 (-)
unnamed: C22.2, R39.2, R47.1, R55.1, U4.2 (-)
unnamed: C23.2, R40.2, R48.1, R56.1, U4.6 (-)
unnamed: C24.2, R41.2, R49.1, R57.1, U5.2 (-)
unnamed: C25.2, R42.2, R50.1, R58.1, U5.6 (-)
unnamed: C38.2, R71.2, R79.1, U6.2 (-)
unnamed: C34.2, R67.2, R75.1, U6.6 (-)
unnamed: C39.2, R72.2, R80.1, U7.2 (-)
unnamed: C35.2, R68.2, R76.1, U7.6 (-)
unnamed: C40.2, R73.2, R81.1, U8.2 (-)
unnamed: C36.2, R69.2, R77.1, U8.6 (-)
unnamed: C41.2, R74.2, R82.1, U9.2 (-)
unnamed: C37.2, R70.2, R78.1, U9.6 (-)
unnamed: C46.2, R99.2, R101.1, U10.2 (-)
unnamed: C47.2, R100.2, R102.1, U10.6 (-)
unnamed: C45.1, R96.2, U11.2 (-)
unnamed: C44.1, R95.2, U11.6 (-)

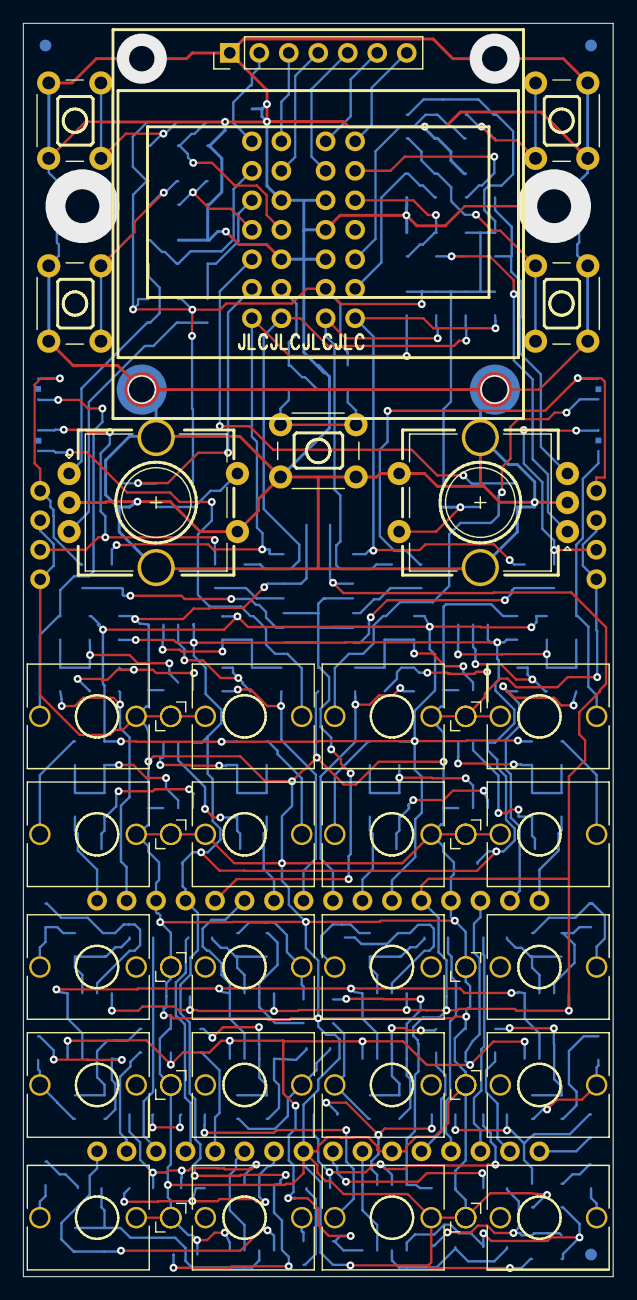
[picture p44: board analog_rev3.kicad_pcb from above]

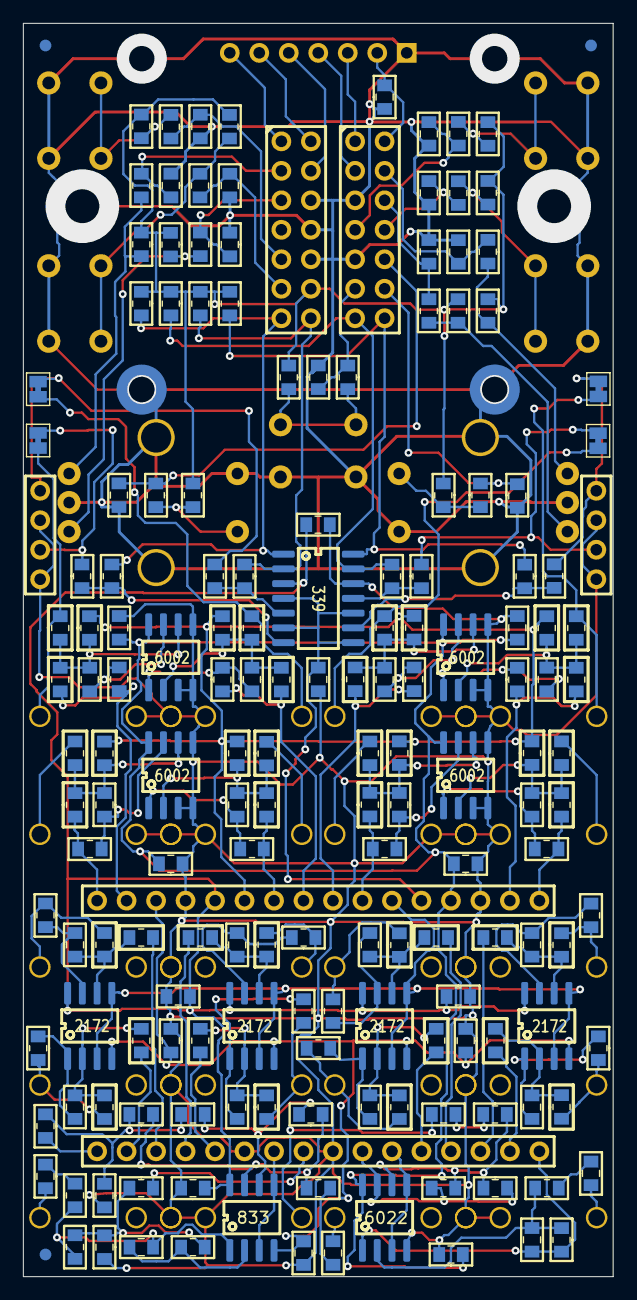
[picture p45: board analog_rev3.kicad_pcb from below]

Board: 2 copper layers, 50.8 x 107.9 mm, 202 parts (174 on the bottom side), 135 nets.

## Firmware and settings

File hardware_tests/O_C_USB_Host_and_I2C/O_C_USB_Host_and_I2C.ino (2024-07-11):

#include <USBHost_t36.h>
#include <Wire.h>

USBHost myusb;
USBHub hub1(myusb);
USBHub hub2(myusb);
MIDIDevice midi1(myusb);

void setup()
{
  Wire.begin();
  while (!Serial) ; // wait for Arduino Serial Monitor
  Serial.println("USB Host Testing and I2C Scan");
  myusb.begin();
  midi1.setHandleNoteOff(OnNoteOff);
  midi1.setHandleNoteOn(OnNoteOn);
  midi1.setHandleControlChange(OnControlChange);
}


void loop()
{
  myusb.Task();
  midi1.read();
  static elapsedMillis msec;
  if (msec > 2000) {
    msec = 0;
    Serial.println(F("Scanning Wire..."));
    scan(Wire);
  }
}



void OnNoteOn(byte channel, byte note, byte velocity)
{
  Serial.print("Note On, ch=");
  Serial.print(channel);
  Serial.print(", note=");
  Serial.print(note);
  Serial.print(", velocity=");
  Serial.print(velocity);
  Serial.println();
}

void OnNoteOff(byte channel, byte note, byte velocity)
{
  Serial.print("Note Off, ch=");
  Serial.print(channel);
  Serial.print(", note=");
  Serial.print(note);
  //Serial.print(", velocity=");
  //Serial.print(velocity);
  Serial.println();
}

void OnControlChange(byte channel, byte control, byte value)
{
  Serial.print("Control Change, ch=");
  Serial.print(channel);
  Serial.print(", control=");
  Serial.print(control);
  Serial.print(", value=");
  Serial.print(value);
  Serial.println();
}

void scan(TwoWire &myport) {
  int nDevices = 0;
  for (int address = 1; address < 127; address++) {
    // The i2c_scanner uses the return value of
    // the Write.endTransmisstion to see if
    // a device did acknowledge to the address.
    myport.beginTransmission(address);
    int error = myport.endTransmission();

    if (error == 0) {
      Serial.print(F("Device found at address 0x"));
      if (address < 16) {
        Serial.print("0");
      }
      Serial.print(address,HEX);
      Serial.print("  (");
      printKnownChips(address);
      Serial.println(")");
      nDevices++;
    } else if (error==4) {
      Serial.print(F("Unknown error at address 0x"));
      if (address < 16) {
        Serial.print("0");
      }
      Serial.println(address,HEX);
    }
  }
  if (nDevices == 0) {
    Serial.println(F("No I2C devices found"));
  } else {
    Serial.println(F("done"));
  }
  Serial.println();
}


void printKnownChips(byte address)
{
  // Is this list missing part numbers for chips you use?
  // Please suggest additions here:
  // https://github.com/PaulStoffregen/Wire/issues/new
  switch (address) {
    case 0x00: Serial.print(F("AS3935")); break;
    case 0x01: Serial.print(F("AS3935")); break;
    case 0x02: Serial.print(F("AS3935")); break;
    case 0x03: Serial.print(F("AS3935")); break;
    case 0x04: Serial.print(F("ADAU1966")); break;
    case 0x0A: Serial.print(F("SGTL5000")); break; // MCLK required
    case 0x0B: Serial.print(F("SMBusBattery?")); break;
    case 0x0C: Serial.print(F("AK8963")); break;
    case 0x10: Serial.print(F("CS4272")); break;
    case 0x11: Serial.print(F("Si4713")); break;
    case 0x13: Serial.print(F("VCNL4000,AK4558")); break;
    case 0x18: Serial.print(F("LIS331DLH")); break;
    case 0x19: Serial.print(F("LSM303,LIS331DLH")); break;
    case 0x1A: Serial.print(F("WM8731")); break;
    case 0x1C: Serial.print(F("LIS3MDL")); break;
    case 0x1D: Serial.print(F("LSM303D,LSM9DS0,ADXL345,MMA7455L,LSM9DS1,LIS3DSH")); break;
    case 0x1E: Serial.print(F("LSM303D,HMC5883L,FXOS8700,LIS3DSH")); break;
    case 0x20: Serial.print(F("MCP23017,MCP23008,PCF8574,FXAS21002,SoilMoisture")); break;
    case 0x21: Serial.print(F("MCP23017,MCP23008,PCF8574")); break;
    case 0x22: Serial.print(F("MCP23017,MCP23008,PCF8574")); break;
    case 0x23: Serial.print(F("MCP23017,MCP23008,PCF8574")); break;
    case 0x24: Serial.print(F("MCP23017,MCP23008,PCF8574,ADAU1966,HM01B0")); break;
    case 0x25: Serial.print(F("MCP23017,MCP23008,PCF8574")); break;
    case 0x26: Serial.print(F("MCP23017,MCP23008,PCF8574")); break;
    case 0x27: Serial.print(F("MCP23017,MCP23008,PCF8574,LCD16x2,DigoleDisplay")); break;
    case 0x28: Serial.print(F("BNO055,EM7180,CAP1188")); break;
    case 0x29: Serial.print(F("TSL2561,VL6180,TSL2561,TSL2591,BNO055,CAP1188")); break;
    case 0x2A: Serial.print(F("SGTL5000,CAP1188")); break;
    case 0x2B: Serial.print(F("CAP1188")); break;
    case 0x2C: Serial.print(F("MCP44XX ePot")); break;
    case 0x2D: Serial.print(F("MCP44XX ePot")); break;
    case 0x2E: Serial.print(F("MCP44XX ePot")); break;
    case 0x2F: Serial.print(F("MCP44XX ePot")); break;
    case 0x30: Serial.print(F("Si7210")); break;
    case 0x31: Serial.print(F("Si7210")); break;
    case 0x32: Serial.print(F("Si7210")); break;
    case 0x33: Serial.print(F("MAX11614,MAX11615,Si7210,MLX90640,MLX90641")); break;
    case 0x34: Serial.print(F("MAX11612,MAX11613")); break;
    case 0x35: Serial.print(F("MAX11616,MAX11617")); break;
    case 0x38: Serial.print(F("RA8875,FT6206,MAX98390")); break;
    case 0x39: Serial.print(F("TSL2561, APDS9960")); break;
    case 0x3A: Serial.print(F("MLX90632")); break;
    case 0x3C: Serial.print(F("SSD1306,DigisparkOLED")); break;
    case 0x3D: Serial.print(F("SSD1306")); break;
    case 0x40: Serial.print(F("PCA9685,Si7021,MS8607")); break;
    case 0x41: Serial.print(F("STMPE610,PCA9685")); break;
    case 0x42: Serial.print(F("PCA9685")); break;
    case 0x43: Serial.print(F("PCA9685")); break;
    case 0x44: Serial.print(F("PCA9685, SHT3X, ADAU1966")); break;
    case 0x45: Serial.print(F("PCA9685, SHT3X")); break;
    case 0x46: Serial.print(F("PCA9685")); break;
    case 0x47: Serial.print(F("PCA9685")); break;
    case 0x48: Serial.print(F("ADS1115,PN532,TMP102,LM75,PCF8591,CS42448")); break;
    case 0x49: Serial.print(F("ADS1115,TSL2561,PCF8591,CS42448,TC74A1")); break;
    case 0x4A: Serial.print(F("ADS1115,Qwiic Keypad,CS42448")); break;
    case 0x4B: Serial.print(F("ADS1115,TMP102,BNO080,Qwiic Keypad,CS42448")); break;
    case 0x50: Serial.print(F("EEPROM,FRAM")); break;
    case 0x51: Serial.print(F("EEPROM")); break;
    case 0x52: Serial.print(F("Nunchuk,EEPROM")); break;
    case 0x53: Serial.print(F("ADXL345,EEPROM")); break;
    case 0x54: Serial.print(F("EEPROM")); break;
    case 0x55: Serial.print(F("EEPROM")); break;
    case 0x56: Serial.print(F("EEPROM")); break;
    case 0x57: Serial.print(F("EEPROM")); break;
    case 0x58: Serial.print(F("TPA2016,MAX21100")); break;
    case 0x5A: Serial.print(F("MPR121,MLX90614")); break;
    case 0x60: Serial.print(F("MPL3115,MCP4725,MCP4728,TEA5767,Si5351")); break;
    case 0x61: Serial.print(F("MCP4725,AtlasEzoDO")); break;
    case 0x62: Serial.print(F("LidarLite,MCP4725,AtlasEzoORP")); break;
    case 0x63: Serial.print(F("MCP4725,AtlasEzoPH")); break;
    case 0x64: Serial.print(F("AtlasEzoEC, ADAU1966")); break;
    case 0x66: Serial.print(F("AtlasEzoRTD")); break;
    case 0x68: Serial.print(F("DS1307,DS3231,MPU6050,MPU9050,MPU9250,ITG3200,ITG3701,LSM9DS0,L3G4200D")); break;
    case 0x69: Serial.print(F("MPU6050,MPU9050,MPU9250,ITG3701,L3G4200D")); break;
    case 0x6A: Serial.print(F("LSM9DS1")); break;
    case 0x6B: Serial.print(F("LSM9DS0")); break;
    case 0x6F: Serial.print(F("Qwiic Button")); break;
    case 0x70: Serial.print(F("HT16K33,TCA9548A")); break;
    case 0x71: Serial.print(F("SFE7SEG,HT16K33")); break;
    case 0x72: Serial.print(F("HT16K33")); break;
    case 0x73: Serial.print(F("HT16K33")); break;
    case 0x76: Serial.print(F("MS5607,MS5611,MS5637,BMP280")); break;
    case 0x77: Serial.print(F("BMP085,BMA180,BMP280,MS5611")); break;
    case 0x7C: Serial.print(F("FRAM_ID")); break;
    default: Serial.print(F("unknown chip"));
  }
}

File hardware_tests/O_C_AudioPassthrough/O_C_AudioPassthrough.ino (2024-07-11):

#include <Audio.h>

AudioInputI2S2       i2s1;
AudioOutputI2S2      i2s2;
AudioAnalyzePeak     peak_L;
AudioAnalyzePeak     peak_R;
AudioConnection      patchCord1(i2s1, 0, i2s2, 0);
AudioConnection      patchCord2(i2s1, 1, i2s2, 1);
AudioConnection      patchCord3(i2s1, 0, peak_L, 0);
AudioConnection      patchCord4(i2s1, 1, peak_R, 0);

void setup() {
  AudioMemory(12);
}

void loop() {
  static elapsedMillis msec;
  uint8_t cnt;

  if (msec > 24) {
    msec = 0;
    uint8_t leftPeak=peak_L.read() * 30.0;
    uint8_t rightPeak=peak_R.read() * 30.0;
    for(cnt=0;cnt<30-leftPeak;cnt++) {
      Serial.print(" ");
    }
    while(cnt++<30) {
      Serial.print("<");
    }
    Serial.print("||");
    for(cnt=0;cnt<rightPeak;cnt++) {
      Serial.print(">");
    }
    while(cnt++<30) {
      Serial.print(" ");
    }
    Serial.println();
  }
}

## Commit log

2024-06-25 Add bill of materials
2024-07-11 Add hardware test Arduino sketches
2024-07-11 Minor fixes
    [analog_rev3.kicad_sch]
2024-07-11 More minor fixes
    [control_rev3.kicad_sch]
2024-07-11 Add PCB photos
2024-07-11 Another minor fix
    [control_rev3.kicad_sch]
2024-07-13 Update schematics, CC BY-SA with attribution to mxmxmx
    [analog_rev3.kicad_sch, control_rev3.kicad_sch]
2024-07-18 Fix R118 on control board schematic
    [control_rev3.kicad_sch]
2024-12-12 Add resistor part numbers
2025-02-05 Add gerber files
2025-02-05 Update BOM
2025-02-11 Add links to BOM text file
2025-03-06 Add aux panel files from Beau Seidon
    [OCT41_auxpanel_midi_usb.kicad_pcb]
2025-05-21 Add KiCad SMTA parts placement files from Angia on Discord
2025-08-02 converted gerbers to kicad_pcb files and added/customized footprints. generated new gerbers for testing and comparison.
    still a few nuisance DRC warnings, mostly footprint quirks and silkscreen overlap, etc.
    pcb files expect the included Custom_Footprints library to be added to the project
    [analog_rev3.kicad_pcb, analog_rev3.kicad_sch, control_rev3.kicad_pcb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]
2025-08-02 updated usb + din midi expansion panel files
    [OCT41_auxpanel_midi_usb.kicad_pcb]
2025-08-05 added D6 per Paul's recommendation, to help protect U17
    reduced pads on ADC footprint to help prevent solder bridging
    updated a few footprint silkscreens to look more like original rev3 board
    generated updated gerber zip files
    TODO: update IC pads to match more closely to original rev3 board if it makes soldering easier
    [analog_rev3.kicad_pcb, analog_rev3.kicad_sch, control_rev3.kicad_pcb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]
2025-08-08 Document diode D6 which protects U17 during unusual power startup
2025-08-09 Explain USB host and device purpose in readme
2026-01-03 Rename directories for easy access to new version
    [OCT41_auxpanel_midi_usb.kicad_pcb, analog_rev3.kicad_pcb, analog_rev3.kicad_sch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]
2026-01-07 printed PDF of updated control_rev3 schematic including D6 and U26 note
2026-01-07 fixed R97-98 value typo. was 3.84k, is now 3.48k
    [analog_rev3.kicad_sch]
2026-01-07 created a 14 HP faceplate and 2x 2 HP expansion PCBs for USB, triggers, and TRS MIDI
    [14HP_PANEL.kicad_pcb, 2HP_EXP_RIGHT.kicad_pcb, 2HP_EXP_RIGHT.kicad_sch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]
2026-01-07 fixed 14 panel copper layer overhang, generated gerber files, and created BOM for expansion panels
    [14HP_PANEL.kicad_pcb, 2HP_EXP_RIGHT.kicad_pcb, 2HP_EXT_LEFT.kicad_pcb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]
2026-01-07 flipped order of USB and MIDI wire/header holes to avoid crossing wires. also made front panel even fancier.
    [2HP_EXP_RIGHT.kicad_pcb, 2HP_EXT_LEFT.kicad_pcb]
2026-01-07 fixed USB-C Dev Port pulldown resistor value! oops.
    original wrong 4.7K value was within spec's 20% tolerance but 5.1K is correct.
    [2HP_EXT_LEFT.kicad_pcb, 2HP_EXT_LEFT.kicad_sch]
2026-01-07 Added MIDI Out jumpers to expanders, updated USB-C exp to be universal with pads for dev or host resistors, renamed files and created all new gerbers, added readme and fixed BOM.
    [2HP_EXP (USB-A).kicad_pcb, 2HP_EXP (USB-A).kicad_sch, 2HP_EXP_RIGHT.kicad_pcb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]
2026-01-07 BOM fixup, added gerber subfolder
    [BOM.csv]
2026-01-07 renamed files for JLC upload compatibility
    [2HP_EXP_USB_A.kicad_pcb, 2HP_EXP_USB_A.kicad_sch, 2HP_EXT_USB_C.kicad_pcb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]
2026-03-28 Rename folder, change spaces to underscores
    [2HP_EXP_USB_A.kicad_pcb, 2HP_EXP_USB_A.kicad_sch, 2HP_EXT_USB_C.kicad_pcb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]
2026-03-30 Add another 14hp photo with 2hp boards
2026-05-22 Update readme, link to Phazerville's ID voltages documentation

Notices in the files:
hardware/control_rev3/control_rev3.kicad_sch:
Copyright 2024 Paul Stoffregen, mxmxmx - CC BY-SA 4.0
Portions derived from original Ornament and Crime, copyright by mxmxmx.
